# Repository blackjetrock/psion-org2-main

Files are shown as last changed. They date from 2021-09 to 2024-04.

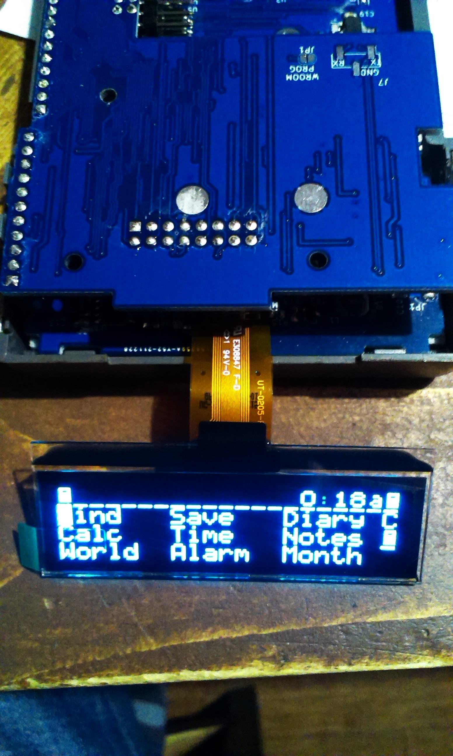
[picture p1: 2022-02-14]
photos/display/IMAG1578.jpg

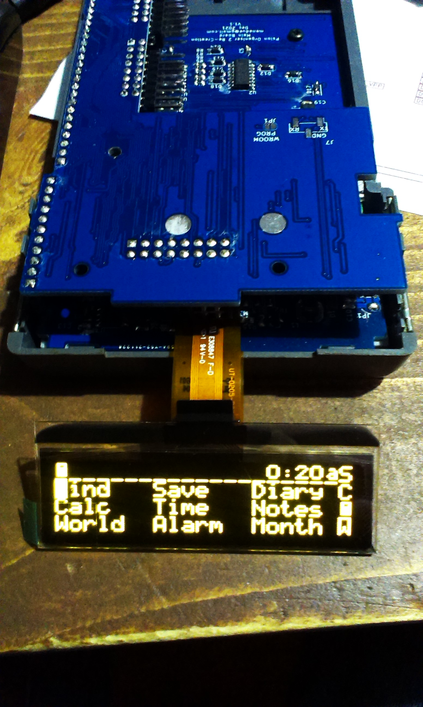
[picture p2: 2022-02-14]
photos/display/IMAG1577.jpg

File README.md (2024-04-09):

# Psion Organiser 2 Recreation Main PCB

A recreation of the Psion Organiser II main PCB using a RP Pico as the
main processor.
An OLED display replaces the original LCD, datapack gadgets supply the
non volatile storage using SD cards.
A ESP-WROOM-32 module on the board provides Wifi and maybe Bluetooth connectivity.
The module provides a hot spot that can be used to perfom actions on the Organiser
and transfer data.

The code running will hopefully be an emulation of the 6303 running one of the original
organiser ROMs with the hardware emulation done on the Pico.

Main PCB
========

This has a RP Pico on it as a controller and several IO expanders. These are because the Pico doesn't have enough GPIOs to
run all of the hardware that is needed.

Power PCB
=========

The original power PCB doesn't really fit with the new main board, so rather than try to work around it, A new PCB is used with the
new main board. It has the slot connectors and any hardware needed to drive them. The slot level shifters are on this board. It would be possible to design a different poiwer PCB that, for example, didn't have slots but had sd cards instead. The hardware for the slots is then replaced by the new PCB, but the main PCB still has whatever circuitry is needed for its own hardware.

Emulator
========

It's a bit of an odd place for it, but there is an emulator here that I used as the basis for the emulator that runs on the recreation. I did the bulk of the work on it on a PC and then moved i tto the Pico. There's now separate code for the Pico as it supports hardware on the main PCB rather than PC based keyboard and display IO. The mon-emulator is a monitored emulator that uses a second emulator to check the operation of mine so that I could find some tricky bugs. The emulator that does the monitoring is the 6303 file from Jaap's Jape emulator, ported to C.

Display
=======

The display is an OLED dot matrix graphics display. I have tried several colours, they all work, the white display is clearest I think.

IMAG1577
IMAG1578
IMAG1580

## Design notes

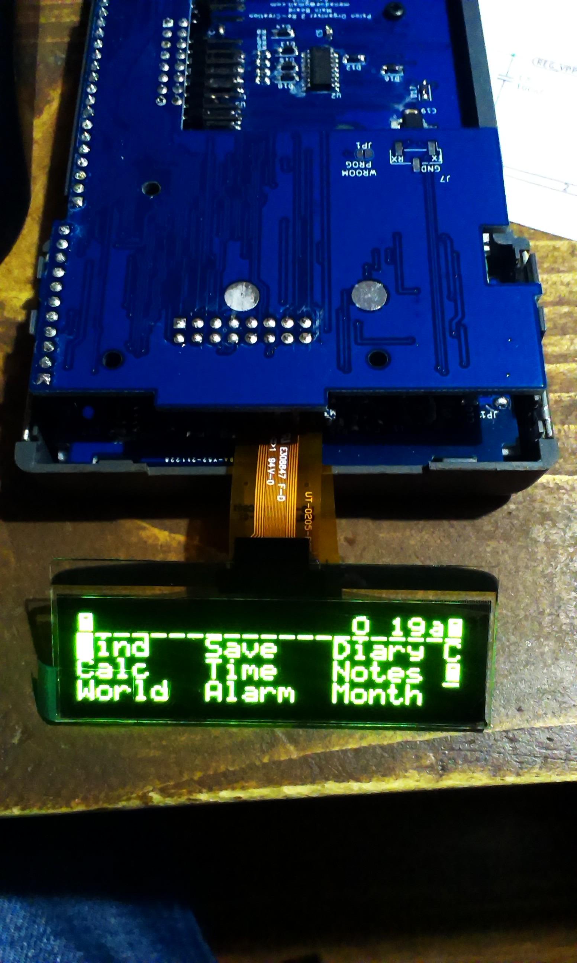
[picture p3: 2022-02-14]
photos/display/IMAG1580.jpg

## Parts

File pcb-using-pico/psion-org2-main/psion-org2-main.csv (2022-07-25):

Id | Designator | Package | Quantity | Designation | Supplier and ref
1 | U5,U2 | SOIC-16_3.9x9.9mm_P1.27mm | 2 | 74HC595
2 | D10,D11 | D_SOD-123 | 2 | 4v7
3 | R18,R25,R15,R10,R24,R14,R13,R1 | R_0805_2012Metric | 8 | 10k
4 | TR1 | SOT-23 | 1 | Si2302CDS-n-ch
5 | D18,D17,D16,D15,D14,D13,D12,D5,D4,D3 | D_SOD-123 | 10 | 1N4148
6 | C7,C6,C5,C22,C3 | C_0805_2012Metric | 5 | 100nF
7 | J3 | PinHeader_1x27_P2.54mm_Vertical | 1 | Conn_01x27_Female
8 | D9,D8 | D_SOD-123 | 2 | AECQ101
9 | J6 | PinHeader_1x11_P2.54mm_Vertical | 1 | Conn_01x11_Female
10 | Y1 | Crystal_SMD_3215-2Pin_3.2x1.5mm | 1 | 32k768Hz
11 | U7 | SO-8_3.9x4.9mm_P1.27mm | 1 | MCP7940N-xSN
12 | R28 | R_0805_2012Metric | 1 | 47k
13 | R27,R11 | R_0805_2012Metric | 2 | 110k
14 | M3,M2,M1 | SOT-23 | 3 | Si2301
15 | D7 | D_SOD-123 | 1 | nopop
16 | C16,C13 | C_0805_2012Metric | 2 | 10pF
17 | TR2 | SOT-23 | 1 | Si2302CDS-n-channel
18 | R17 | R_0805_2012Metric | 1 | nopop
19 | R16 | R_0805_2012Metric | 1 | 2k2
20 | JP6,JP4,JP2 | SolderJumper-2_P1.3mm_Open_RoundedPad1.0x1.5mm | 3 | Jumper_NO_Small
21 | D6 | D_SOD-123 | 1 | 2v7
22 | D2 | D_SOD-123 | 1 | MBR120VLSFT1G
23 | J5,J4 | PinHeader_1x02_P2.54mm_Vertical_SMD_Pin1Left | 2 | Conn_01x02_Female
24 | D1 | D_SOD-123 | 1 | SS36
25 | U4 | SOIC-16_3.9x9.9mm_P1.27mm | 1 | 74LS165
26 | J1 | TE_2-1734839-4_1x24-1MP_P0.5mm_Horizontal_reversed_pinout | 1 | Conn_01x24_Female
27 | SW31 | fx502p_keypad | 1 | right
28 | SW36 | fx502p_keypad | 1 | exe
29 | SW35 | fx502p_keypad | 1 | x
30 | SW34 | fx502p_keypad | 1 | r
31 | SW33 | fx502p_keypad | 1 | L
32 | SW32 | fx502p_keypad | 1 | f
33 | SW30 | fx502p_keypad | 1 | spc
34 | SW29 | fx502p_keypad | 1 | w
35 | SW28 | fx502p_keypad | 1 | q
36 | SW27 | fx502p_keypad | 1 | k
37 | SW26 | fx502p_keypad | 1 | e
38 | SW25 | fx502p_keypad | 1 | left
39 | SW24 | fx502p_keypad | 1 | z
40 | SW23 | fx502p_keypad | 1 | v
41 | SW22 | fx502p_keypad | 1 | p
42 | SW21 | fx502p_keypad | 1 | j
43 | SW20 | fx502p_keypad | 1 | d
44 | SW19 | fx502p_keypad | 1 | down
45 | SW18 | fx502p_keypad | 1 | y
46 | SW17 | fx502p_keypad | 1 | u
47 | SW16 | fx502p_keypad | 1 | o
48 | SW15 | fx502p_keypad | 1 | i
49 | SW14 | fx502p_keypad | 1 | c
50 | SW13 | fx502p_keypad | 1 | up
51 | SW12 | fx502p_keypad | 1 | del
52 | SW11 | fx502p_keypad | 1 | t
53 | SW10 | fx502p_keypad | 1 | n
54 | SW9 | fx502p_keypad | 1 | h
55 | SW8 | fx502p_keypad | 1 | b
56 | SW7 | fx502p_keypad | 1 | mode
57 | SW6 | fx502p_keypad | 1 | shft
58 | SW5 | fx502p_keypad | 1 | s
59 | SW4 | fx502p_keypad | 1 | m
60 | SW3 | fx502p_keypad | 1 | g
61 | SW2 | fx502p_keypad | 1 | A
62 | SW1 | fx502p_keypad | 1 | AC_ON
63 | U1 | RPi_Pico_SMD | 1 | Pico
64 | R21,R20,R19,R9,R8,R7,R6,R5 | R_0805_2012Metric | 8 | 100k
65 | U10 | SOT-223-3_TabPin2 | 1 | AMS1117-3.3
66 | U3 | SOT-23-6 | 1 | Regulator_Switching_MT3608
67 | R23 | R_0805_2012Metric | 1 | Not tested of calculated yet
68 | R22 | R_0805_2012Metric | 1 | Not tested or calculated yet
69 | R12 | R_0805_2012Metric | 1 | 5789R
70 | R4,R3 | R_0805_2012Metric | 2 | 2k
71 | R2 | R_0805_2012Metric | 1 | 910k
72 | L1 | L_Coilcraft_LPS5030 | 1 | 22uH
73 | JP1 | SolderJumper-2_P1.3mm_Open_RoundedPad1.0x1.5mm | 1 | SolderJumper_2_Open
74 | J2 | PinHeader_1x03_P1.00mm_Vertical_SMD_Pin1Left | 1 | Conn_01x03_Female
75 | C21 | C_1210_3225Metric_Pad1.42x2.65mm_HandSolder | 1 | 10uF
76 | C19,C17 | C_0805_2012Metric | 2 | 100n
77 | C10,C4 | C_1210_3225Metric_Pad1.42x2.65mm_HandSolder | 2 | 22uF
78 | C2 | C_0805_2012Metric | 1 | 4u7 25V
79 | C1 | C_0805_2012Metric | 1 | 4u7

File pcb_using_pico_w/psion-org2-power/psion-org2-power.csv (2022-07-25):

Id | Designator | Package | Quantity | Designation | Supplier and ref
1 | J3 | PinHeader_1x27_P2.54mm_Vertical | 1 | Conn_01x27_Female
2 | J9,J8 | psion_beeper_pad | 2 | Conn_01x01_Female
3 | U8 | SOT-223-3_TabPin2 | 1 | AMS1117-5.0
4 | TR3,TR1 | SOT-23 | 2 | Si2302CDS-n-channel
5 | TR2 | SOT-23 | 1 | Si2302CDS-n-ch
6 | R17,R16,R14,R13,R1,R2 | R_0805_2012Metric | 6 | 10k
7 | R12,R11,R10,R9,R8,R7,R6,R5,R4,R3,R15 | R_0805_2012Metric | 11 | 100k
8 | M2,M1 | SOT-23 | 2 | P-CHANNEL-MOSFET
9 | JP1 | SolderJumper-2_P1.3mm_Open_RoundedPad1.0x1.5mm | 1 | Jumper_NO_Small
10 | J7 | PinHeader_1x03_P2.54mm_Vertical_SMD_Pin1Left | 1 | Conn_01x03_Female
11 | D2 | D_SOD-123 | 1 | 4V7
12 | D1 | D_SOD-123 | 1 | 3V0
13 | C12 | C_0805_2012Metric | 1 | 4u7
14 | C11,C10,C9,C7,C8,C6 | C_0805_2012Metric | 6 | 100n
15 | C5,C4,C3,C2,C1 | C_0805_2012Metric | 5 | 100nF
16 | U7,U6 | TSSOP-20_4.4x6.5mm_P0.65mm | 2 | 74LS245
17 | J6 | PinHeader_1x02_P2.54mm_Vertical_SMD_Pin1Left | 1 | Conn_01x02_Female
18 | J1 | PinHeader_2x08_P2.54mm_Horizontal | 1 | Conn_02x08_Odd_Even
19 | J4,J2 | PinHeader_2x08_P2.54mm_Horizontal_psionSide | 2 | Conn_02x08_Odd_Even
20 | U4,U3 | SOIC-8_3.9x4.9mm_P1.27mm | 2 | CAT24C256
21 | U5 | SOIC-16_3.9x9.9mm_P1.27mm | 1 | 74HC595
22 | J5 | PinHeader_1x11_P2.54mm_Vertical | 1 | Conn_01x11_Female
23 | U2 | SOT-223-3_TabPin2 | 1 | AMS1117-3.3
24 | U1 | ESP32-WROOM-32 | 1 | ESP32-WROOM-32

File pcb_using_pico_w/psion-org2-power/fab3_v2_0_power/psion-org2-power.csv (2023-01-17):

Id | Designator | Package | Quantity | Designation | Supplier and ref
1 | U16 | SOT-23-6 | 1 | Regulator_Switching_MT3608
2 | TR7,TR6,TR2 | SOT-23 | 3 | Si2302CDS-n-ch
3 | R51,R48 | R_0805_2012Metric | 2 | 100R
4 | R50 | R_0805_2012Metric | 1 | 1k2
5 | R49 | R_0805_2012Metric | 1 | 18k
6 | R47 | R_0805_2012Metric | 1 | 5k1
7 | R46 | R_0805_2012Metric | 1 | 180k
8 | R45,R14,R13,R1 | R_0805_2012Metric | 4 | 10k
9 | L2 | L_Coilcraft_LPS5030 | 1 | 22uH
10 | JP7 | SolderJumper-2_P1.3mm_Open_RoundedPad1.0x1.5mm | 1 | SolderJumper_2_Open
11 | JP6 | SolderJumper-2_P1.3mm_Open_RoundedPad1.0x1.5mm | 1 | Jumper_NO_Small
12 | D21 | D_SOD-123 | 1 | SS36
13 | C30,C5,C4 | C_0805_2012Metric | 3 | 100nF
14 | C29 | C_1210_3225Metric_Pad1.33x2.70mm_HandSolder | 1 | 10uF
15 | C28,C27 | C_1210_3225Metric_Pad1.33x2.70mm_HandSolder | 2 | 22uF
16 | J3 | PinHeader_1x27_P2.54mm_Vertical | 1 | Conn_01x27_Female
17 | J9,J8 | psion_beeper_pad | 2 | Conn_01x01_Female
18 | U8 | SOT-223-3_TabPin2 | 1 | AMS1117-5.0
19 | R12,R11,R10,R9,R8,R7,R6,R5,R4,R3,R15 | R_0805_2012Metric | 11 | 100k
20 | D1 | D_SOD-123 | 1 | 3V0
21 | C11,C10,C9,C7,C8,C6 | C_0805_2012Metric | 6 | 100n
22 | U7,U6 | TSSOP-20_4.4x6.5mm_P0.65mm | 2 | 74LS245
23 | M1 | SOT-23 | 1 | P-CHANNEL-MOSFET
24 | TR1 | SOT-23 | 1 | Si2302CDS-n-channel
25 | J6 | PinHeader_1x02_P2.54mm_Vertical_SMD_Pin1Left | 1 | Conn_01x02_Female
26 | J1 | PinHeader_2x08_P2.54mm_Horizontal | 1 | Conn_02x08_Odd_Even
27 | J4,J2 | PinHeader_2x08_P2.54mm_Horizontal_psionSide | 2 | Conn_02x08_Odd_Even
28 | U4,U3 | SOIC-8_3.9x4.9mm_P1.27mm | 2 | CAT24C256
29 | U5 | SOIC-16_3.9x9.9mm_P1.27mm | 1 | 74HC595
30 | J5 | PinHeader_1x11_P2.54mm_Vertical | 1 | Conn_01x11_Female

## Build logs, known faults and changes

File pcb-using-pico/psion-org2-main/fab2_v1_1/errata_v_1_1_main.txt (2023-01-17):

Errata for V1.1 of main PCB
===========================

1. 5V regulator being on power PCB means processor PCB isn't stand alone
   any more as Pico is powered from it. Pico can't use battery voltage.
   I think it could be USB powered in stand alone mode. You'd also
   need a battery though for the other circuitry.
   Or put 5V regulator on processor PCB again?
   Or not have sytand alone any more?
2. R13 should be 10k, due maybe to some leakage across PCB
3. Tracks from R15 to TR2 seems to have leakage on to the gate of TR2,
   causing it to not turn off properly. Changing R13 to 10k and removing
   the track allows TR2 to turn off. re-route track. Chek clearances.
4. R25 has to go to VBAT or there is no voltage to allow the RTC to turn
   on the power
5. 100nF across R13 and R14, and R18. All mosfets.

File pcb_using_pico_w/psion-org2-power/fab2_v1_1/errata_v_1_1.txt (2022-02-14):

Errata for Power PCB V1.1
=========================

1. VPP signal on datapack slots should maybe be +5V
2. Diode fouls top slot plastic. Cut away of plastic needed to get it to
   fit.
3. Mounting hole is about 0.5mm out. Screw can be made to fit but it's not
   perfect.
4. Power PCB may be too short at top as top slot slider doesn't stay in place.

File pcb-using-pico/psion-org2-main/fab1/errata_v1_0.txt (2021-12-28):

V1.0 Psion recreate Main PCB Errata
===================================

DONE SCH     1. S_PGM pin needs to be attached for paged datapacks. Not on edge connector.
                Used pin 10 on edge connector. *added*
DONE     PCB 2. Pin headers don't line up
????         3. Holes missing for top slot Not on main board Done on power PCB
DONE SCH     4. OLED pin 10 should be GND not open.
DONE SCH     5. Top row of keys wired up wrong.
DONE SCH     6. Mislabelled P52 as p52 on keyboard.
DONE SCH     7. Put battery voltage circuit on the 'off' side of ON switch to reduce
                supply current draw when off.
DONE SCH     8. Need a diode on each keyboard drive line to allow shiftkey to work.
DONE SCH     9. Put jumper in so OLED supply can be hard wired to GND. There's about
                3V loss with switch and display doesn't turn off fully anyway. Switched
                3V3 power allows it to be turned off. *removed circuit*
DONE SCH     10. Put jumper for MFP output so it can be disabled. It holds
                 power on when low. Added transistor to prevent VBAT on MFP pin. No jumper
		 as we can leave transistor off if the signal isn't needed. Or resistor.
DONE SCH     11. QH_O not attached to shift register
             12. Possibly put LEDs on the KB side of the PCB for backlighting
???          13. Tie unused 245 inputs? *There isn't one on this PCB*
             14. Put buck boost regulator on for 5V so can run from USB supply? No, create
	         a USB supply that has that circuitry due to space and more fexible that way.
DONE SCH     15. VBAT should come from after the diodes that connect to the battery
                 and the external power connector so we have reverse voltage protection.
		 Maybe some signals should come off the battery and not the diode cathodes?
DONE     PCB 16. Put space around mounting holes
DONE     PCB 17. Top slot moulding doesn't fit, move components so it does.
***          18. AC_B input is wrong polarity. pulling low should turn organiser on.
                 Maybe invert logic of keyboard scanning? Put inverter on the power PCB
		 as it's related to the power circuit and top slot. Not really for main
		 PCB. Saves space on main PCB.
DONE     PCB 19. 22uH inductor needs to move, maybe.
DONE     PCB 20. C14 and C15 are badly placed. Renumbered, added decoiupling caps
DONE SCH     21. Decoupling needed for U2,U4,U5
DONE SCH     22. M1,M3 etc need voltage limiting circuits if external power voltage
                 isn't limited. Alternatively limit external power to 8V or whatever
                 M1 etc can operate with. Or swap those transistors for higher voltage
                 rating of Vgs
DONE SCH     23. RTC_MFP has battery voltage on it.
DONE SCH     24. Battery switching needs to limit Vgs. Power needs to be supported up to
                 14V/17V.
DONE LEAVE   25. Buzzer output is OK. Maybe a faster drive? Works ok. Emulation a bit
	         slow so tones not as high
DONE SCH     26. Run buzzer drive to power PCB
DONE SCH     27. JP8 and JP9 not needed. ON can be powered from battery voltage.
DONE SCH     28. Remove JP10 as can just jumper the diode.
***	     29. Running off 5V would be nice. Put dc-dc etc in power adapter as more
                 customizable and flexible, plus not much room on PCBs now.
DONE SCH PCB 30. Take 5V regulator for slots off main PCB.
	     
Tasks
=====
1. Check all key connections. Done.

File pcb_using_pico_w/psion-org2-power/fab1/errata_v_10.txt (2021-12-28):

V1.0 Psion recreate Power PCB Errata
===================================

DONE SCH     1. S_PGM pin needs to be attached for paged datapacks.
DONE SCH     2. SPGM not on edge connector
DONE SCH PCB 3. Put pads on PCB for beeper springs
             4. Put buck boost for running off USB supply on this PCB? Maybe
	        better on processor PCB? If just for datapacks then power PCB.
		Use external power pack from usb to ext power in.
DONE SCH PCB 5. Pull downs on pack slot connector side of SDx databus
	        lines needed.
DONE SCH PCB 6. Switch supply of WROOM with 2 transistor switch from
	        VBAT_SWITCHED2 into 3V3 regulator.
DONE     PCB 7. Screw post hits U7
****         8. External power filter/protection? No, put on external PSU
DONE SCH     9. Add connections for programming the WROOM
DONE SCH PCB 10. Limit Vgs on mosfets.
DONE SCH     11. IO0 to GND for programming mode
                 TXD0 and RXD0 to RXD and TXD
DONE SCH     12. Tie unused 245 to GND?
DONE SCH     13. Invert EX_ON signal. VBAT powered.
DONE SCH     14. Buzzer signal run in to board pin 14
DONE SCH     15. Why is 5V regulator on processor PCB? It powers the slots and
		 they are a power PCB funtion.
DONE         16. Check outline of top slot plastic moulding

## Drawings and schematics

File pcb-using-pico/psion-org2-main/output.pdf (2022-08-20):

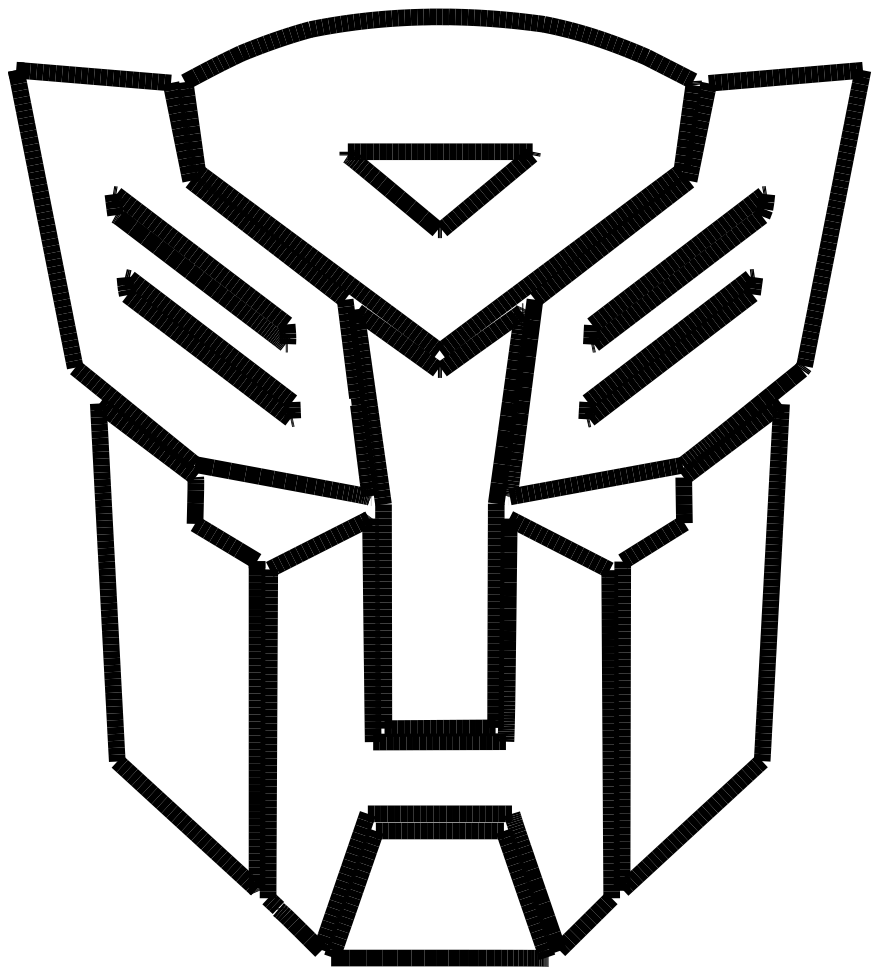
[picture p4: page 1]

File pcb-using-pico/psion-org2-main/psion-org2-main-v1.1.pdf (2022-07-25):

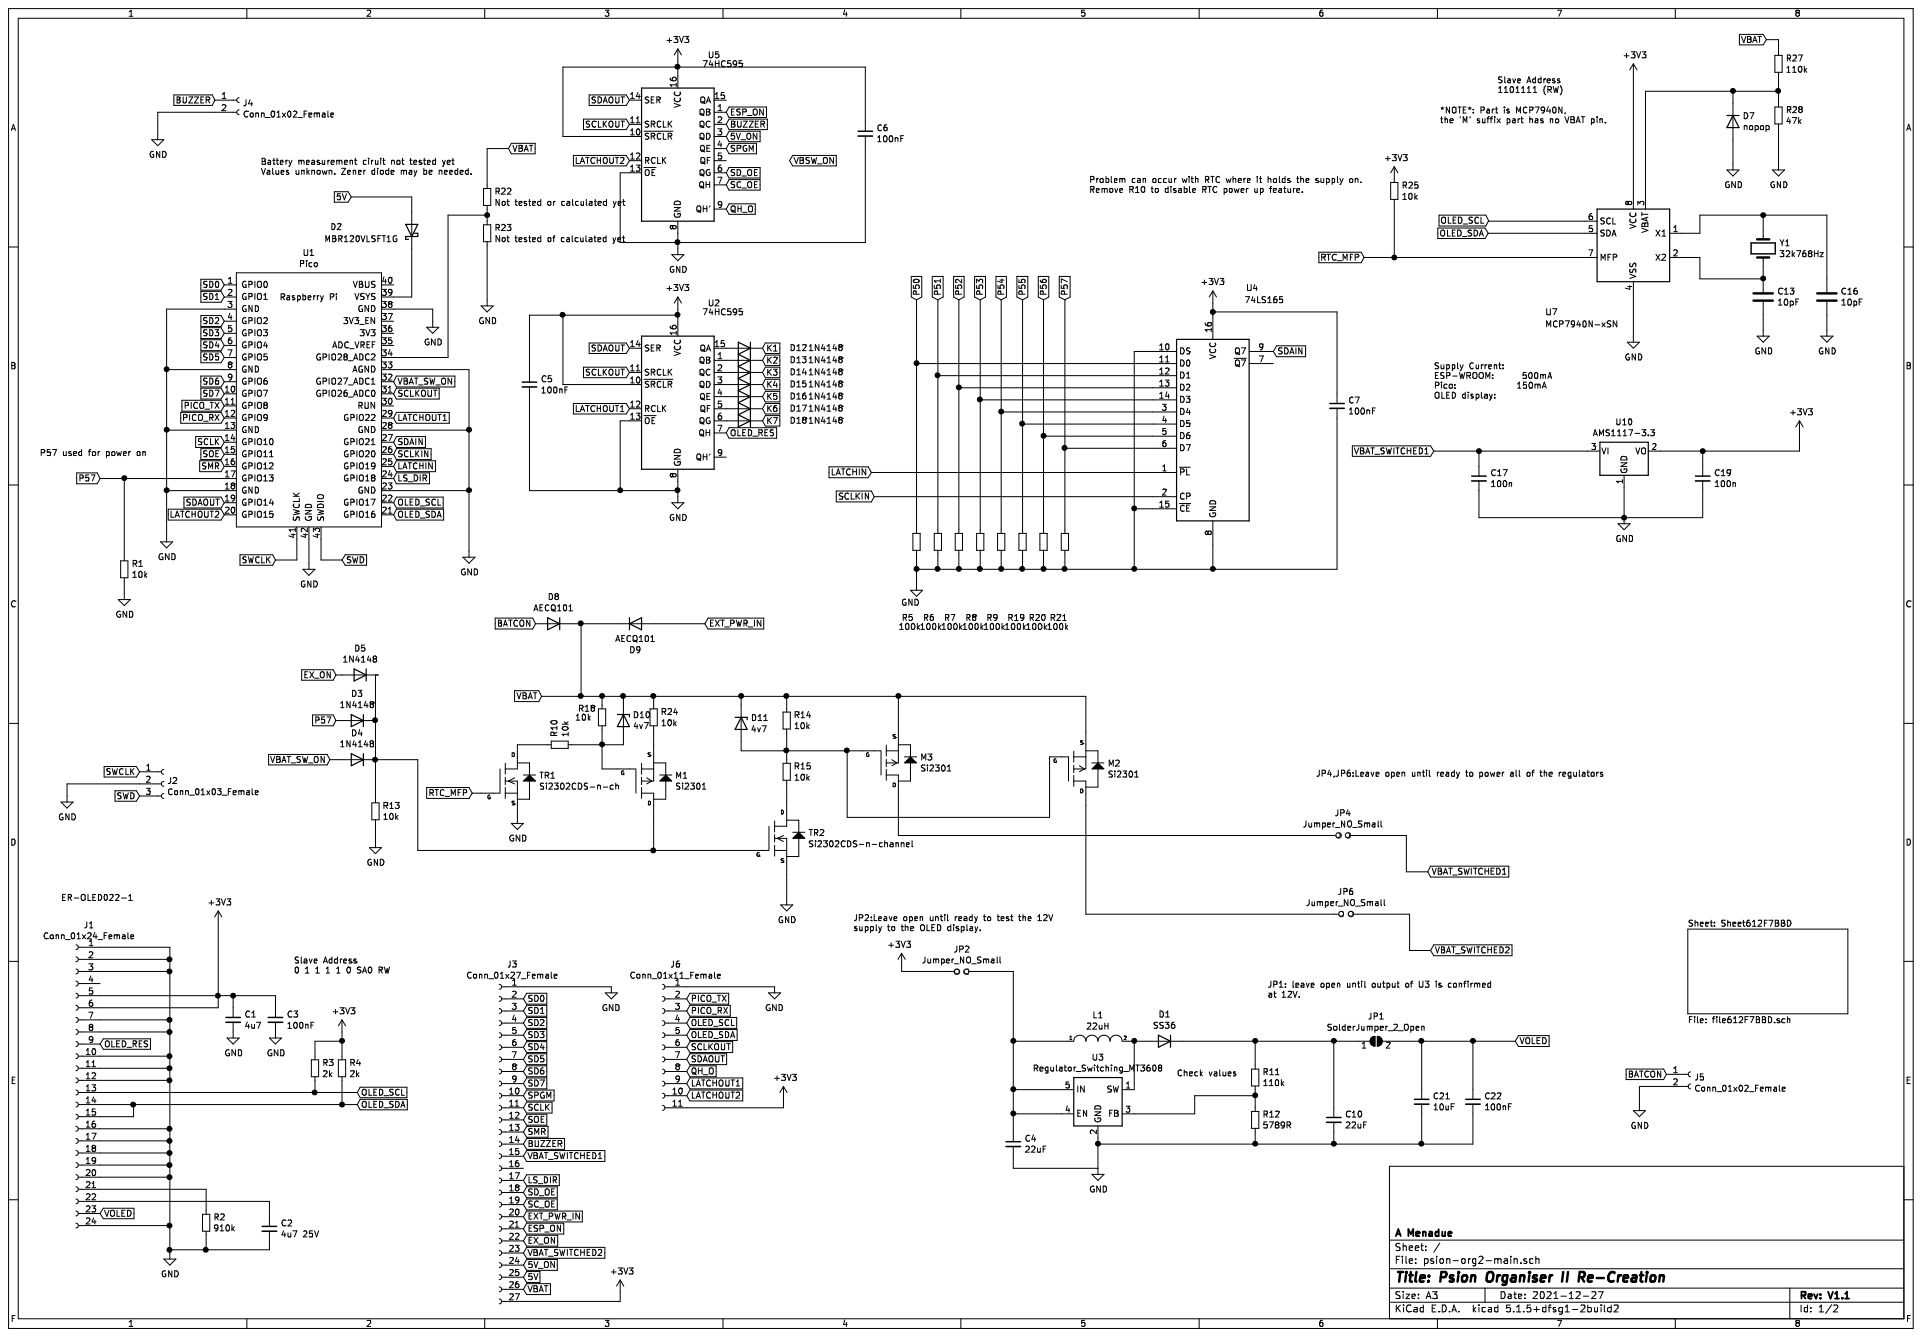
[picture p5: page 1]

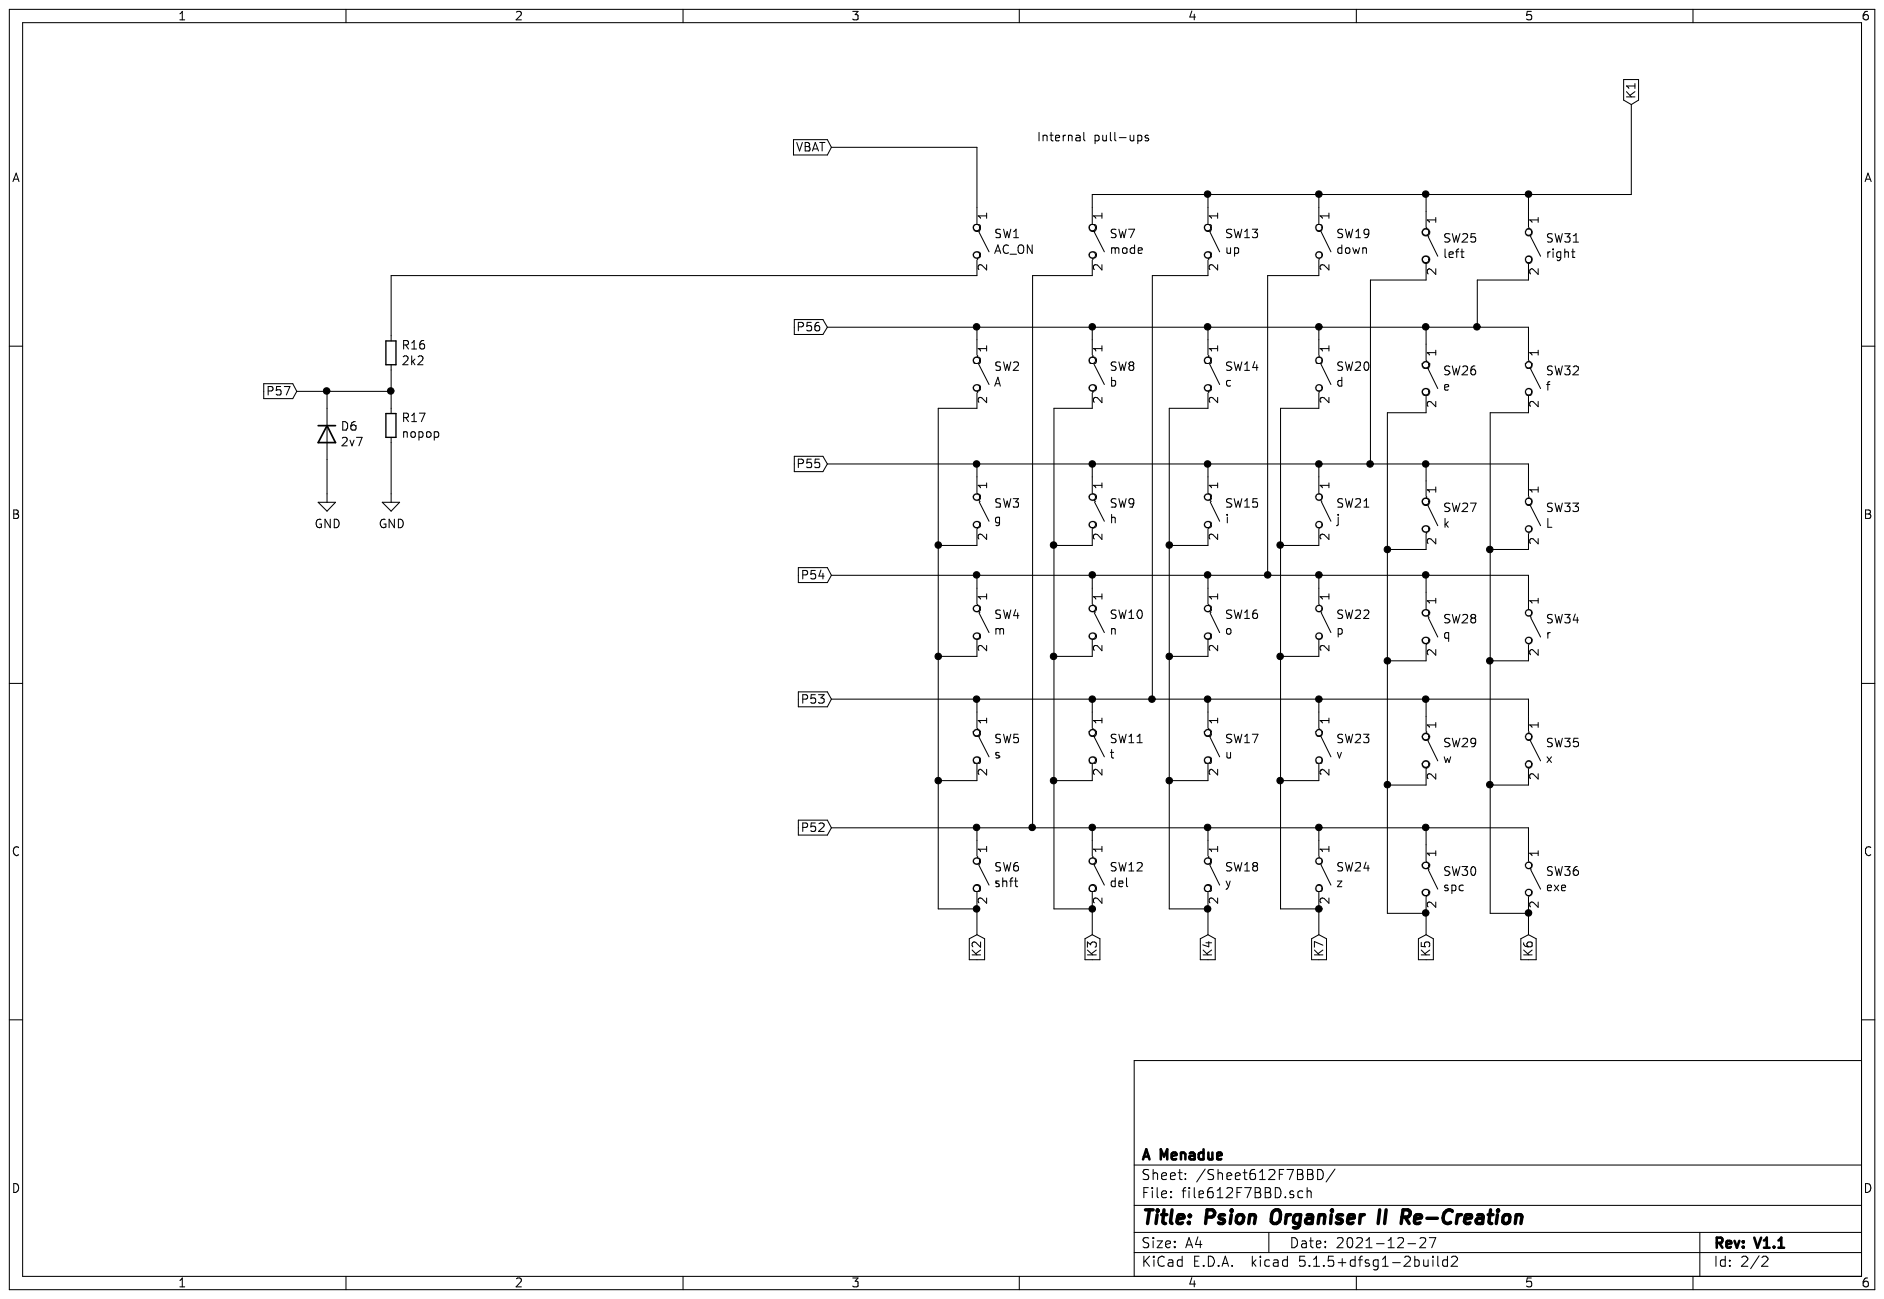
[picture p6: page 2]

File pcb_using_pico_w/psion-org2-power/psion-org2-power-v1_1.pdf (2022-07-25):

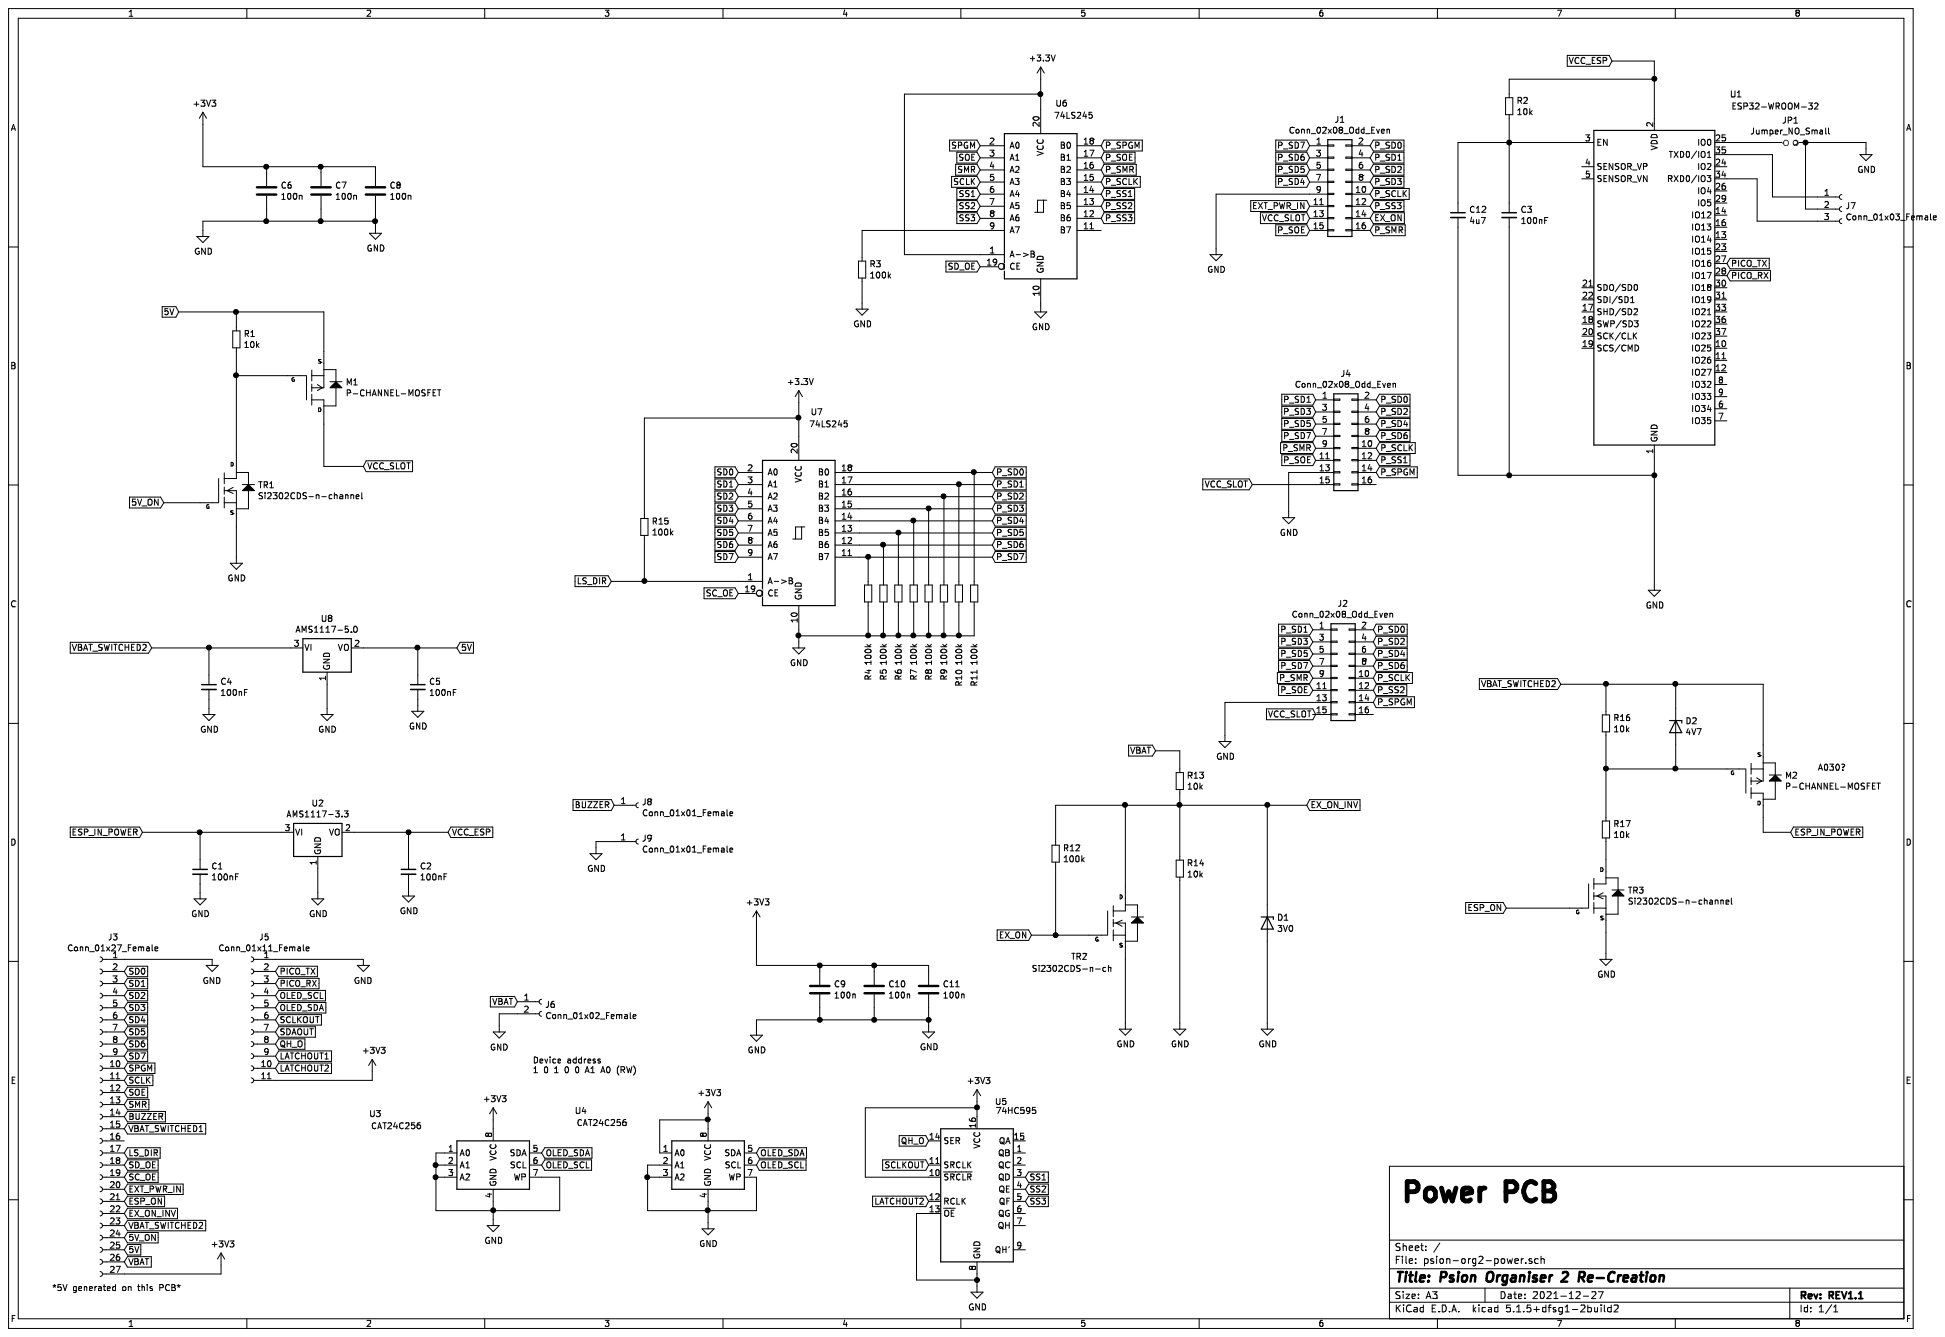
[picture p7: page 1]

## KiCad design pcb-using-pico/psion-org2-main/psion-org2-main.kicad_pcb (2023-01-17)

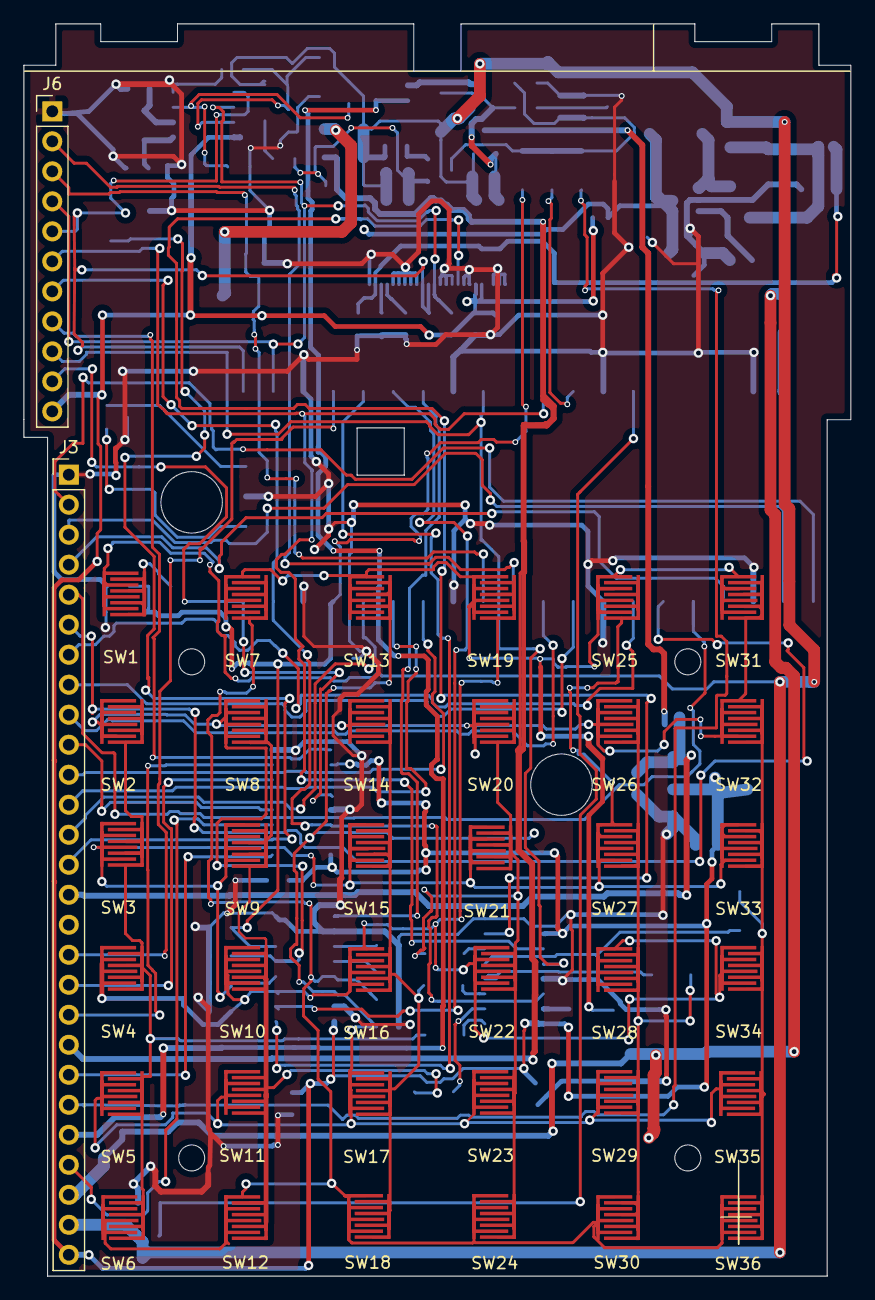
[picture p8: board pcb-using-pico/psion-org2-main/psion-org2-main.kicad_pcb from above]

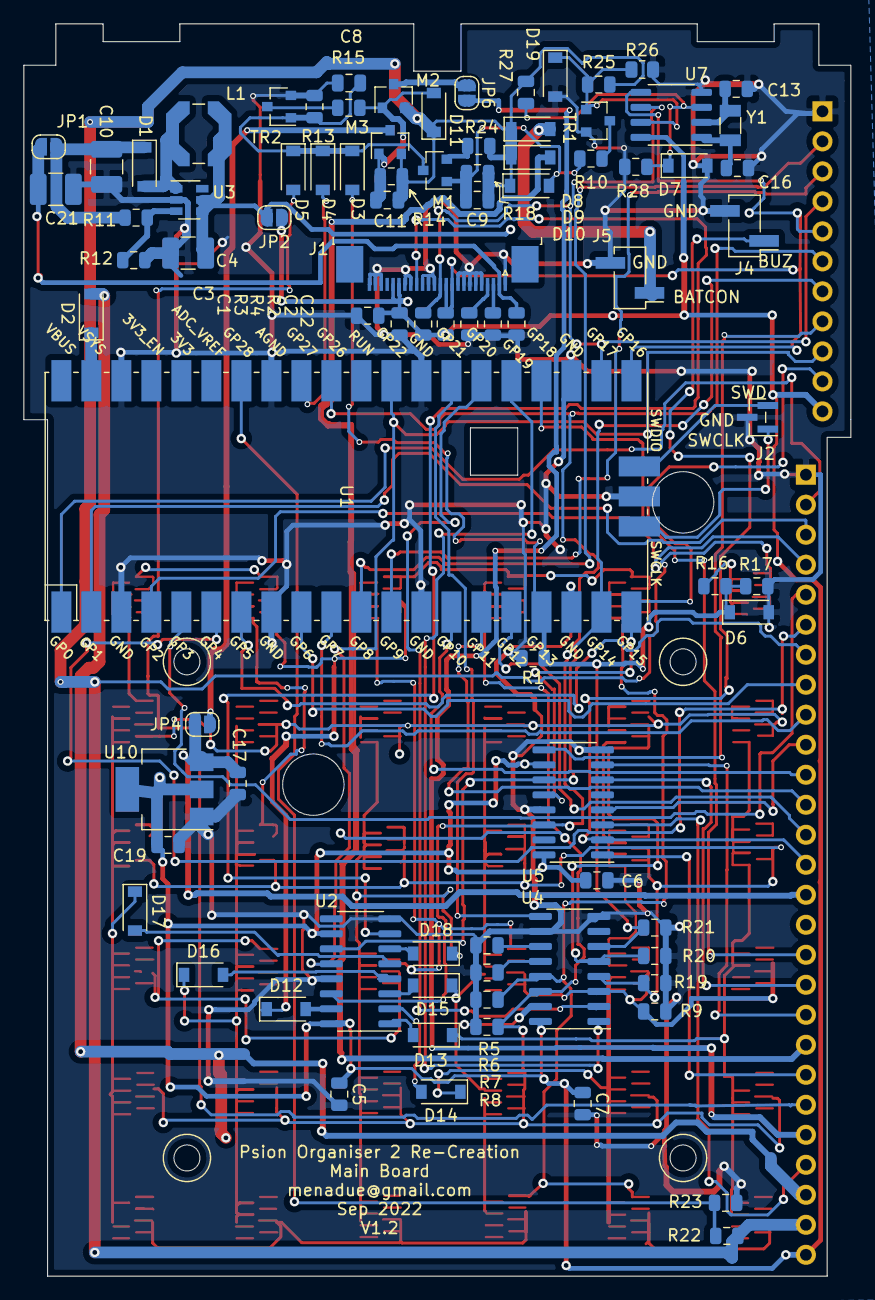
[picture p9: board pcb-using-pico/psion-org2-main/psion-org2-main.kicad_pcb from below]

Board: 2 copper layers, 70.0 x 106.0 mm, 124 parts (86 on the bottom side), 87 nets.

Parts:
C1: 4u7; C_0805_2012Metric
C2: 4u7 25V; C_0805_2012Metric
C3, C5, C6, C7, C8, C9, C11, C22: 100nF; C_0805_2012Metric
C4, C10: 22uF; C_1210_3225Metric_Pad1.42x2.65mm_HandSolder
C13, C16: 10pF; C_0805_2012Metric
C17, C19: 100n; C_0805_2012Metric
C21: 10uF; C_1210_3225Metric_Pad1.42x2.65mm_HandSolder
D1: SS36; D_SOD-123
D2: MBR120VLSFT1G; D_SOD-123
D3, D4, D5, D12, D13, D14, D15, D16, D17, D18: 1N4148; D_SOD-123
D6: 2v7; D_SOD-123
D7, D19: nopop; D_SOD-123
D8, D9: AECQ101; D_SOD-123
D10, D11: 4v7; D_SOD-123
J1: Conn_01x24_Female; TE_2-1734839-4_1x24-1MP_P0.5mm_Horizontal_reversed_pinout
J2: Conn_01x03_Female; PinHeader_1x03_P1.00mm_Vertical_SMD_Pin1Left
J3: Conn_01x27_Female; PinHeader_1x27_P2.54mm_Vertical
J4, J5: Conn_01x02_Female; PinHeader_1x02_P2.54mm_Vertical_SMD_Pin1Left
J6: Conn_01x11_Female; PinHeader_1x11_P2.54mm_Vertical
JP1: SolderJumper_2_Open; SolderJumper-2_P1.3mm_Open_RoundedPad1.0x1.5mm
JP2, JP4, JP6: Jumper_NO_Small; SolderJumper-2_P1.3mm_Open_RoundedPad1.0x1.5mm
L1: 22uH; L_Coilcraft_LPS5030
M1, M2, M3: Si2301; SOT-23
R1, R10, R13, R14, R15, R18, R24, R25, R26: 10k; R_0805_2012Metric
R2: 910k; R_0805_2012Metric
R3, R4: 2k; R_0805_2012Metric
R5, R6, R7, R8, R9, R19, R20, R21: 100k; R_0805_2012Metric
R11, R27: 110k; R_0805_2012Metric
R12: 5789R; R_0805_2012Metric
R16: 2k2; R_0805_2012Metric
R17: nopop; R_0805_2012Metric
R22: Not tested or calculated yet; R_0805_2012Metric
R23: Not tested of calculated yet; R_0805_2012Metric
R28: 47k; R_0805_2012Metric
SW1: AC_ON; fx502p_keypad
SW2: A; fx502p_keypad
SW3: g; fx502p_keypad
SW4: m; fx502p_keypad
SW5: s; fx502p_keypad
SW6: shft; fx502p_keypad
SW7: mode; fx502p_keypad
SW8: b; fx502p_keypad
SW9: h; fx502p_keypad
SW10: n; fx502p_keypad
SW11: t; fx502p_keypad
SW12: del; fx502p_keypad
SW13: up; fx502p_keypad
SW14: c; fx502p_keypad
SW15: i; fx502p_keypad
SW16: o; fx502p_keypad
SW17: u; fx502p_keypad
SW18: y; fx502p_keypad
SW19: down; fx502p_keypad
SW20: d; fx502p_keypad
SW21: j; fx502p_keypad
SW22: p; fx502p_keypad
SW23: v; fx502p_keypad
SW24: z; fx502p_keypad
SW25: left; fx502p_keypad
SW26: e; fx502p_keypad
SW27: k; fx502p_keypad
SW28: q; fx502p_keypad
SW29: w; fx502p_keypad
SW30: spc; fx502p_keypad
SW31: right; fx502p_keypad
SW32: f; fx502p_keypad
SW33: L; fx502p_keypad
SW34: r; fx502p_keypad
SW35: x; fx502p_keypad
SW36: exe; fx502p_keypad
TR1: Si2302CDS-n-ch; SOT-23
TR2: Si2302CDS-n-channel; SOT-23
U1: Pico; RPi_Pico_SMD
U2, U5: 74HC595; SOIC-16_3.9x9.9mm_P1.27mm
U3: Regulator_Switching_MT3608; SOT-23-6
U4: 74LS165; SOIC-16_3.9x9.9mm_P1.27mm
U7: MCP7940N-xSN; SO-8_3.9x4.9mm_P1.27mm
U10: AMS1117-3.3; SOT-223-3_TabPin2
Y1: 32k768Hz; Crystal_SMD_3215-2Pin_3.2x1.5mm

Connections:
5V: D2.2, J3.25
5V_ON: J3.24, U5.3
+3V3: C1.1, C3.1, C5.1, C6.1, C7.1, C19.1, J1.5, J1.6, J3.27, J6.11, JP2.1, R3.1, R4.1, U2.10, U2.16, U4.16, U5.10, U5.16, U7.8, U10.2
BATCON: D8.2, J5.1
BUZZER: J3.14, J4.1, U5.2
ESP_ON: J3.21, U5.1
EXT_PWR_IN: D9.2, J3.20
EX_ON: D5.2, J3.22
GND: C1.2, C2.2, C3.2, C4.2, C5.2, C6.2, C7.2, C8.2, C10.2, C13.2, C16.2, C17.2, C19.2, C21.2, C22.2, D6.2, D7.2, D19.2, J1.1, J1.2, J1.3, J1.7, J1.8, J1.10, J1.11, J1.12, J1.16, J1.17, J1.18, J1.19, J1.20, J1.24, J2.2, J3.1, J4.2, J5.2, J6.1, R1.2, R2.2, R5.2, R6.2, R7.2, R8.2, R9.2, R12.2, R13.2, R17.2, R19.2, R20.2, R21.2, R23.2, R26.2, R28.2, TR1.2, TR2.2, U1.3, U1.8, U1.13, U1.18, U1.23, U1.28, U1.33, U1.38, U1.42, U2.8, U2.13, U3.2, U4.8, U4.10, U4.15, U5.8, U5.13, U7.4, U10.1
K1: D12.1, SW7.1, SW13.1, SW19.1, SW25.1, SW31.1
K2: D13.1, SW2.2, SW3.2, SW4.2, SW5.2, SW6.2
K3: D14.1, SW8.2, SW9.2, SW10.2, SW11.2, SW12.2
K4: D15.1, SW14.2, SW15.2, SW16.2, SW17.2, SW18.2
K5: D16.1, SW26.2, SW27.2, SW28.2, SW29.2, SW30.2
K6: D17.1, SW32.2, SW33.2, SW34.2, SW35.2, SW36.2
K7: D18.1, SW20.2, SW21.2, SW22.2, SW23.2, SW24.2
LATCHIN: U1.25, U4.1
LATCHOUT1: J6.9, U1.29, U2.12
LATCHOUT2: J6.10, U1.20, U5.12
LS_DIR: J3.17, U1.24
unnamed: C2.1, J1.22
unnamed: C4.1, JP2.2, L1.1, U3.4, U3.5
unnamed: C8.1, D3.1, D4.1, D5.1, M1.3, R13.1, TR2.1
unnamed: C9.2, D10.2, M1.1, R10.2, R18.2
unnamed: C10.1, D1.1, JP1.1, R11.1
unnamed: C11.2, D11.2, M2.1, M3.1, R14.2, R15.1
unnamed: C13.1, U7.2, Y1.2
unnamed: C16.1, U7.1, Y1.1
unnamed: D1.2, L1.2, U3.1
unnamed: D2.1, U1.39
unnamed: D7.1, R27.2, R28.1, U7.3
unnamed: D12.2, U2.15
unnamed: D13.2, U2.1
unnamed: D14.2, U2.2
unnamed: D15.2, U2.3
unnamed: D16.2, U2.4
unnamed: D17.2, U2.5
unnamed: D18.2, U2.6
unnamed: J1.21, R2.1
unnamed: JP4.1, M3.3
unnamed: JP6.1, M2.3
unnamed: M1.2, R24.2
unnamed: R10.1, TR1.3
unnamed: R11.2, R12.1, U3.3
unnamed: R15.2, TR2.3
unnamed: R16.1, SW1.2
unnamed: R22.2, R23.1, U1.34
OLED_RES: J1.9, U2.7
OLED_SCL: J1.13, J6.4, R3.2, U1.22, U7.6
OLED_SDA: J1.14, J1.15, J6.5, R4.2, U1.21, U7.5
P50: R5.1, U4.11
P51: R6.1, U4.12
P52: R7.1, SW6.1, SW7.2, SW12.1, SW18.1, SW24.1, SW30.1, SW36.1, U4.13
P53: R8.1, SW5.1, SW11.1, SW13.2, SW17.1, SW23.1, SW29.1, SW35.1, U4.14
P54: R9.1, SW4.1, SW10.1, SW16.1, SW19.2, SW22.1, SW28.1, SW34.1, U4.3
P55: R19.1, SW3.1, SW9.1, SW15.1, SW21.1, SW25.2, SW27.1, SW33.1, U4.4
P56: R20.1, SW2.1, SW8.1, SW14.1, SW20.1, SW26.1, SW31.2, SW32.1, U4.5
P57: D3.2, D6.1, R1.1, R16.2, R17.1, R21.1, U1.17, U4.6
PICO_RX: J6.3, U1.12
PICO_TX: J6.2, U1.11
QH_O: J6.8, U5.9
RTC_MFP: D19.1, R25.2, R26.1, TR1.1, U7.7
SCLK: J3.11, U1.14
SCLKIN: U1.26, U4.2
SCLKOUT: J6.6, U1.31, U2.11, U5.11
SC_OE: J3.19, U5.7
SD0: J3.2, U1.1
SD1: J3.3, U1.2
SD2: J3.4, U1.4
SD3: J3.5, U1.5
SD4: J3.6, U1.6
SD5: J3.7, U1.7
SD6: J3.8, U1.9
SD7: J3.9, U1.10
SDAIN: U1.27, U4.9
SDAOUT: J6.7, U1.19, U2.14, U5.14
SD_OE: J3.18, U5.6
SMR: J3.13, U1.16
SOE: J3.12, U1.15
SPGM: J3.10, U5.4
SWCLK: J2.1, U1.41
SWD: J2.3, U1.43
VBAT: C9.1, C11.1, D8.1, D9.1, D10.1, D11.1, J3.26, M2.2, M3.2, R14.1, R18.1, R22.1, R24.1, R25.1, R27.1, SW1.1
VBAT_SWITCHED1: C17.1, J3.15, JP4.2, U10.3
VBAT_SWITCHED2: J3.23, JP6.2
VBAT_SW_ON: D4.2, U1.32
VOLED: C21.1, C22.1, J1.23, JP1.2

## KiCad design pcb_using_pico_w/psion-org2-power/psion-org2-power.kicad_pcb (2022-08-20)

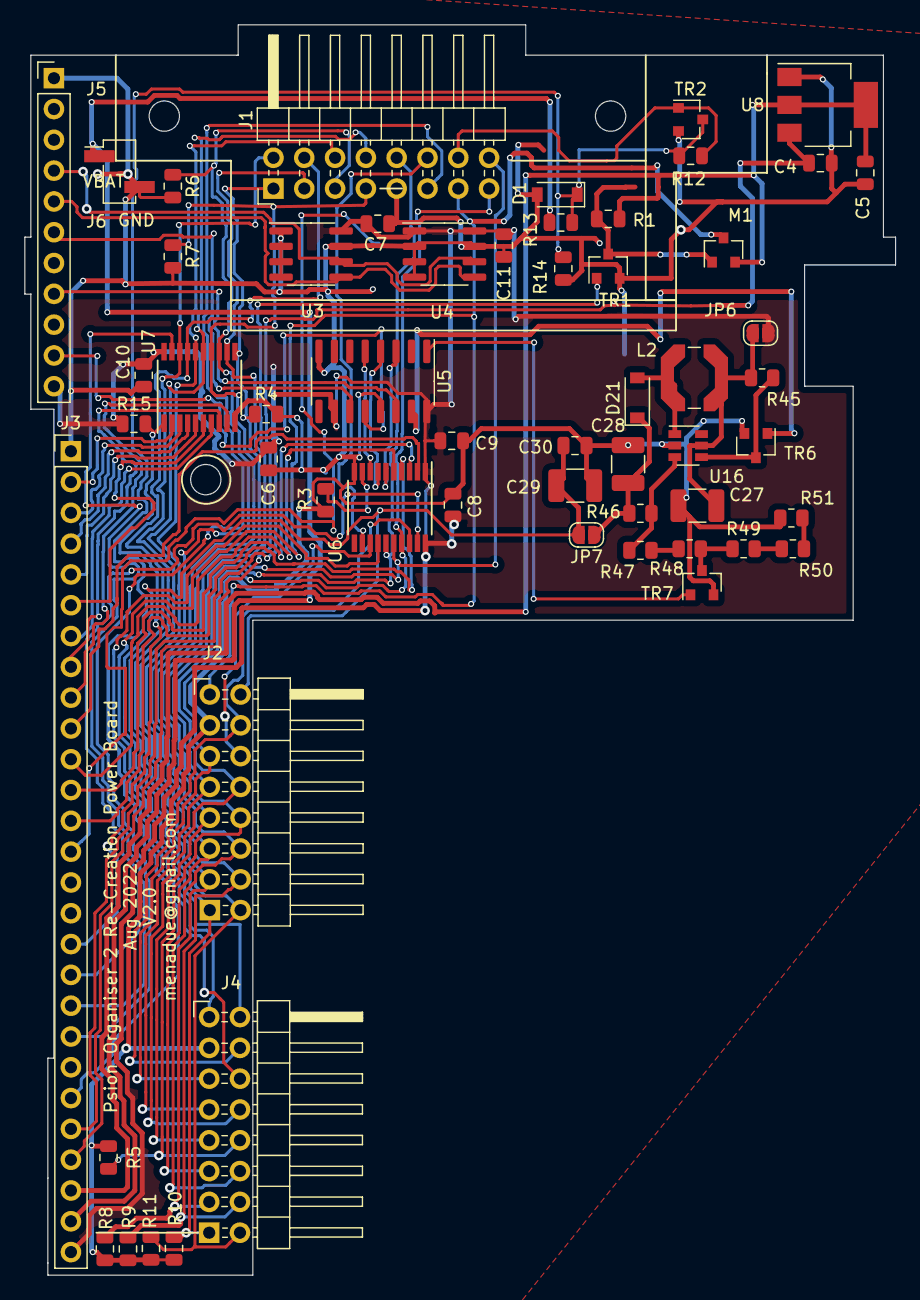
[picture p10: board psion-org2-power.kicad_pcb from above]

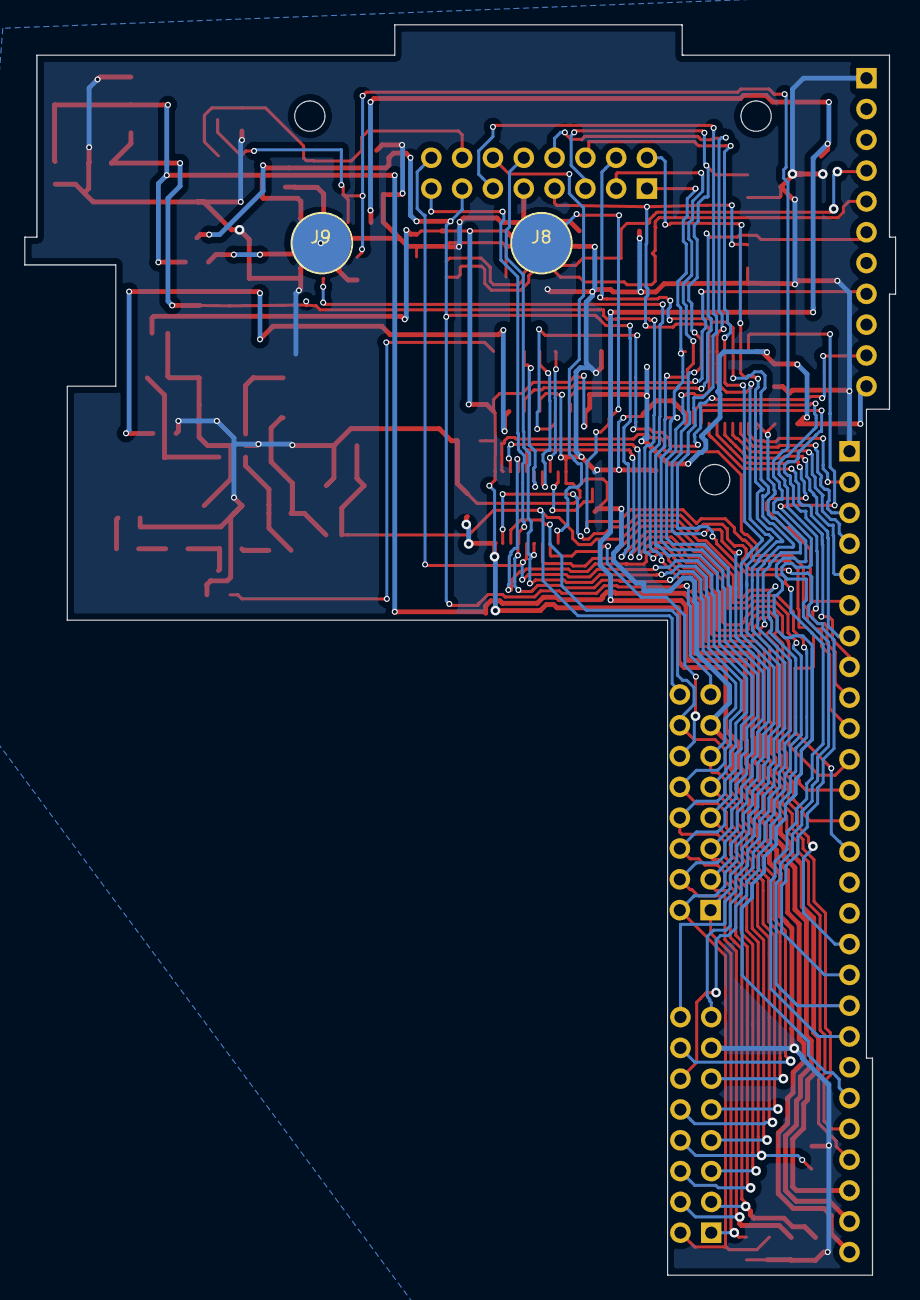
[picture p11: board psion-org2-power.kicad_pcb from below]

Board: 2 copper layers, 71.8 x 103.1 mm, 58 parts (2 on the bottom side), 63 nets.

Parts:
C4, C5, C30: 100nF; C_0805_2012Metric
C6, C7, C8, C9, C10, C11: 100n; C_0805_2012Metric
C27, C28: 22uF; C_1210_3225Metric_Pad1.33x2.70mm_HandSolder
C29: 10uF; C_1210_3225Metric_Pad1.33x2.70mm_HandSolder
D1: 3V0; D_SOD-123
D21: SS36; D_SOD-123
J1: Conn_02x08_Odd_Even; PinHeader_2x08_P2.54mm_Horizontal
J2, J4: Conn_02x08_Odd_Even; PinHeader_2x08_P2.54mm_Horizontal_psionSide
J3: Conn_01x27_Female; PinHeader_1x27_P2.54mm_Vertical
J5: Conn_01x11_Female; PinHeader_1x11_P2.54mm_Vertical
J6: Conn_01x02_Female; PinHeader_1x02_P2.54mm_Vertical_SMD_Pin1Left
J8, J9: Conn_01x01_Female; psion_beeper_pad
JP6: Jumper_NO_Small; SolderJumper-2_P1.3mm_Open_RoundedPad1.0x1.5mm
JP7: SolderJumper_2_Open; SolderJumper-2_P1.3mm_Open_RoundedPad1.0x1.5mm
L2: 22uH; L_Coilcraft_LPS5030
M1: P-CHANNEL-MOSFET; SOT-23
R1, R13, R14, R45: 10k; R_0805_2012Metric
R3, R4, R5, R6, R7, R8, R9, R10, R11, R12, R15: 100k; R_0805_2012Metric
R46: 180k; R_0805_2012Metric
R47: 5k1; R_0805_2012Metric
R48, R51: 100R; R_0805_2012Metric
R49: 18k; R_0805_2012Metric
R50: 1k2; R_0805_2012Metric
TR1: Si2302CDS-n-channel; SOT-23
TR2, TR6, TR7: Si2302CDS-n-ch; SOT-23
U3, U4: CAT24C256; SOIC-8_3.9x4.9mm_P1.27mm
U5: 74HC595; SOIC-16_3.9x9.9mm_P1.27mm
U6, U7: 74LS245; TSSOP-20_4.4x6.5mm_P0.65mm
U8: AMS1117-5.0; SOT-223-3_TabPin2
U16: Regulator_Switching_MT3608; SOT-23-6

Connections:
5V: C5.1, J3.25, M1.2, R1.1, U8.2
5V_ON: J3.24, TR1.1
+3V3: C6.1, C7.1, C8.1, C9.1, C10.1, C11.1, J3.27, J5.11, JP6.1, R15.1, U3.8, U4.1, U4.8, U5.10, U5.16, U6.1, U6.20, U7.20
BUZZER: J3.14, J8.1
EXT_PWR_IN: J1.11, J3.20
EX_ON: J1.14, R12.2, TR2.1
EX_ON_INV: D1.1, J3.22, R12.1, R13.2, R14.1, TR2.3
GND: C4.2, C5.2, C6.2, C7.2, C8.2, C9.2, C10.2, C11.2, C27.2, C28.2, C29.2, C30.2, D1.2, J1.9, J2.13, J3.1, J4.13, J5.1, J6.2, J9.1, R3.2, R4.2, R5.2, R6.2, R7.2, R8.2, R9.2, R10.2, R11.2, R14.2, R51.2, TR1.2, TR2.2, TR6.2, TR7.2, U3.1, U3.2, U3.3, U3.4, U3.7, U4.2, U4.3, U4.4, U4.7, U5.8, U5.13, U6.10, U7.10, U8.1, U16.2
LATCHOUT2: J5.10, U5.12
LS_DIR: J3.17, R15.2, U7.1
unnamed: C27.1, JP6.2, L2.1, R45.1, U16.5
unnamed: C28.1, D21.1, JP7.1, R46.1
unnamed: D21.2, L2.2, U16.1
unnamed: M1.1, R1.2, TR1.3
unnamed: R3.1, U6.9
unnamed: R45.2, TR6.3, U16.4
unnamed: R46.2, R47.1, U16.3
unnamed: R47.2, R48.1
unnamed: R48.2, R49.1, TR7.3
unnamed: R49.2, R50.1
unnamed: R50.2, R51.1
OLED_SCL: J5.4, U3.6, U4.6
OLED_SDA: J5.5, U3.5, U4.5
P_SCLK: J1.10, J2.10, J4.10, U6.15
P_SD0: J1.2, J2.2, J4.2, R11.1, U7.18
P_SD1: J1.4, J2.1, J4.1, R10.1, U7.17
P_SD2: J1.6, J2.4, J4.4, R9.1, U7.16
P_SD3: J1.8, J2.3, J4.3, R8.1, U7.15
P_SD4: J1.7, J2.6, J4.6, R7.1, U7.14
P_SD5: J1.5, J2.5, J4.5, R6.1, U7.13
P_SD6: J1.3, J2.8, J4.8, R5.1, U7.12
P_SD7: J1.1, J2.7, J4.7, R4.1, U7.11
P_SMR: J1.16, J2.9, J4.9, U6.16
P_SOE: J1.15, J2.11, J4.11, U6.17
P_SPGM: J2.14, J4.14, U6.18
P_SS1: J4.12, U6.14
P_SS2: J2.12, U6.13
P_SS3: J1.12, U6.12
QH_O: J5.8, U5.14
SCLK: J3.11, U6.5
SCLKOUT: J5.6, U5.11
SC_OE: J3.19, U7.19
SD0: J3.2, U7.2
SD1: J3.3, U7.3
SD2: J3.4, U7.4
SD3: J3.5, U7.5
SD4: J3.6, U7.6
SD5: J3.7, U7.7
SD6: J3.8, U7.8
SD7: J3.9, U7.9
SD_OE: J3.18, U6.19
SMR: J3.13, U6.4
SOE: J3.12, U6.3
SPGM: J3.10, U6.2
SS1: U5.3, U6.6
SS2: U5.4, U6.7
SS3: U5.5, U6.8
VBAT: J3.26, J6.1, R13.1
VBAT_SWITCHED2: C4.1, J3.23, U8.3
VCC_SLOT: J1.13, J2.15, J4.15, M1.3
VPP_DRIVE: C29.1, C30.1, J2.16, J4.16, JP7.2
VPP_ON: TR6.1, U5.15
VPP_VOLT_SELECT: TR7.1, U5.1

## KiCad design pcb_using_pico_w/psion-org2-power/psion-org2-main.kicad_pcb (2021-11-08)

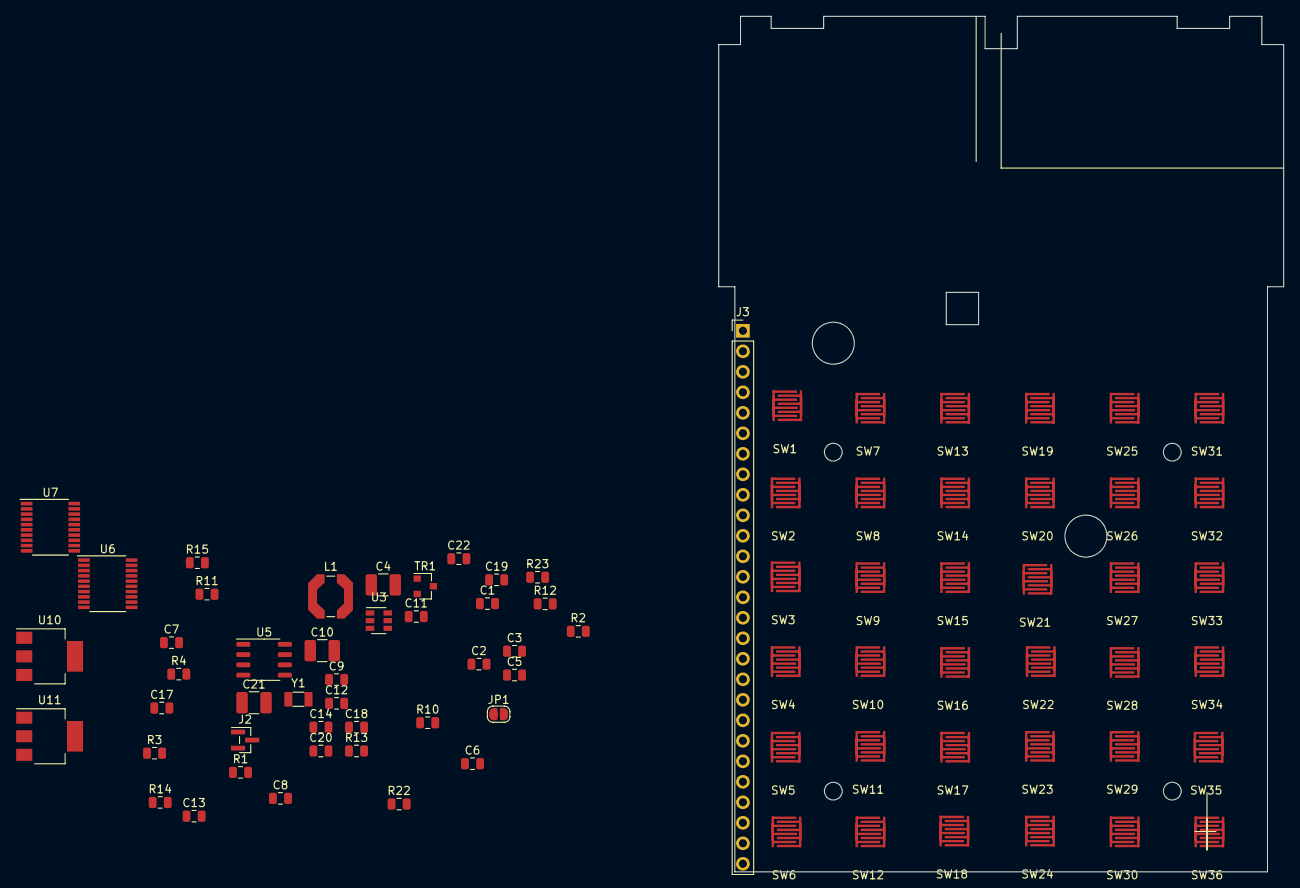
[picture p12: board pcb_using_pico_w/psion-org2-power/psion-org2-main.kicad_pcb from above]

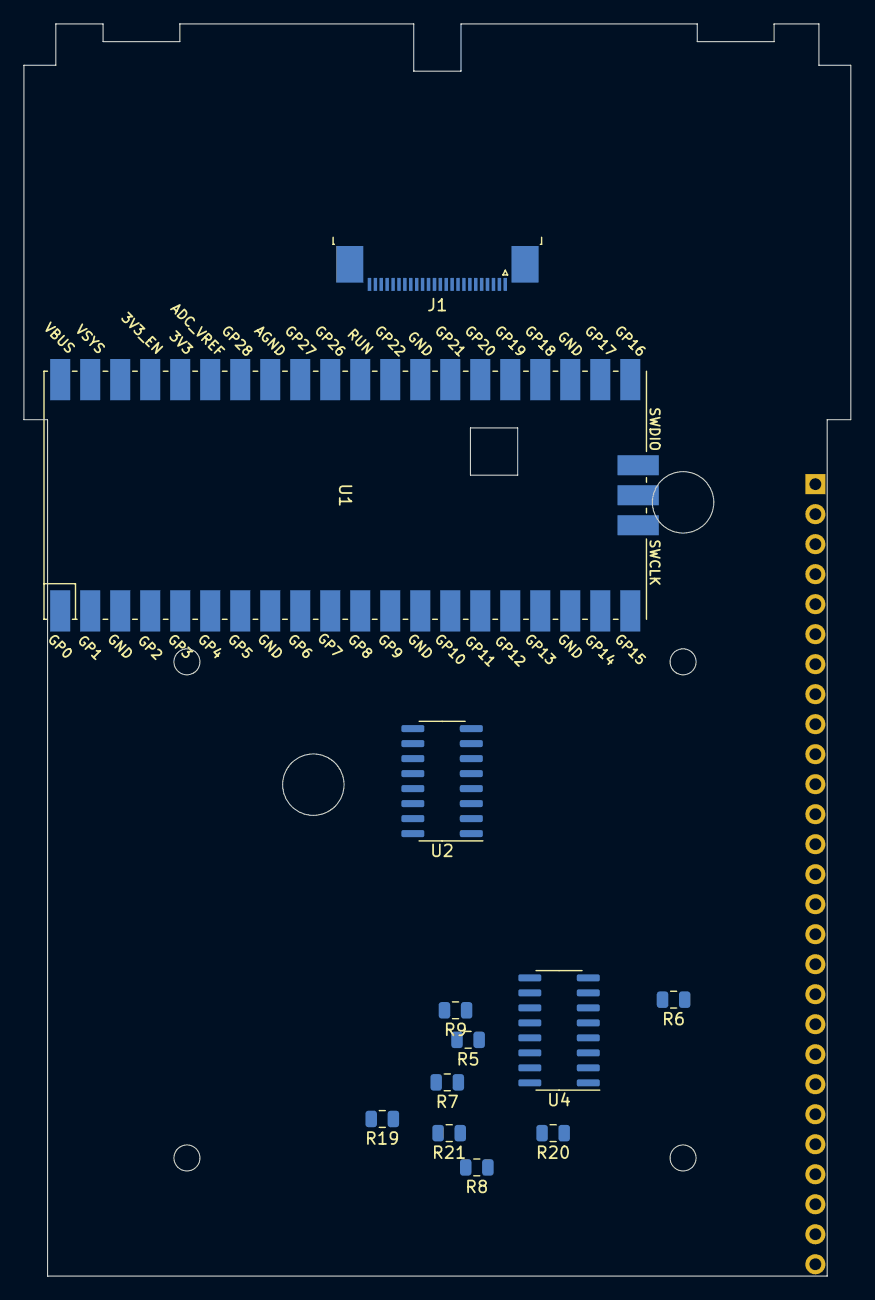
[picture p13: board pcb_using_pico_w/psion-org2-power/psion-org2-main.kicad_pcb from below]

Board: 2 copper layers, 70.0 x 106.0 mm, 92 parts (12 on the bottom side), 73 nets, no tracks yet.

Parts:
C1: 4u7; C_0805_2012Metric
C2: 4u7 25V; C_0805_2012Metric
C3, C22: 100nF; C_0805_2012Metric
C4, C10: 22uF; C_1210_3225Metric_Pad1.42x2.65mm_HandSolder
C5: 1u; C_0805_2012Metric
C6, C7, C8, C9, C11, C12: 100n; C_0805_2012Metric
C13, C14: C; C_0805_2012Metric
C17, C18, C19, C20: C_Small; C_0805_2012Metric
C21: 10uF; C_1210_3225Metric_Pad1.42x2.65mm_HandSolder
J1: Conn_01x24_Female; TE_2-1734839-4_1x24-1MP_P0.5mm_Horizontal_reversed_pinout
J2: Conn_01x03_Female; PinHeader_1x03_P1.00mm_Vertical_SMD_Pin1Left
J3: Conn_01x27_Female; PinHeader_1x27_P2.54mm_Vertical
JP1: SolderJumper_2_Open; SolderJumper-2_P1.3mm_Open_RoundedPad1.0x1.5mm
L1: 22uH; L_Coilcraft_LPS5030
R1, R3, R4: 10k; R_0805_2012Metric
R2: 910k; R_0805_2012Metric
R5, R6, R7, R8, R9, R19, R20, R21: 100k; R_0805_2012Metric
R10: 49R; R_0805_2012Metric
R11: 120k; R_0805_2012Metric
R12: 18k; R_0805_2012Metric
R13, R14: 4k7; R_0805_2012Metric
R15, R22, R23: R_Small; R_0805_2012Metric
SW1: AC_ON; fx502p_keypad
SW2: A; fx502p_keypad
SW3: g; fx502p_keypad
SW4: m; fx502p_keypad
SW5: s; fx502p_keypad
SW6: shft; fx502p_keypad
SW7: mode; fx502p_keypad
SW8: b; fx502p_keypad
SW9: h; fx502p_keypad
SW10: n; fx502p_keypad
SW11: t; fx502p_keypad
SW12: del; fx502p_keypad
SW13: up; fx502p_keypad
SW14: c; fx502p_keypad
SW15: i; fx502p_keypad
SW16: o; fx502p_keypad
SW17: u; fx502p_keypad
SW18: y; fx502p_keypad
SW19: down; fx502p_keypad
SW20: d; fx502p_keypad
SW21: j; fx502p_keypad
SW22: p; fx502p_keypad
SW23: v; fx502p_keypad
SW24: z; fx502p_keypad
SW25: left; fx502p_keypad
SW26: e; fx502p_keypad
SW27: k; fx502p_keypad
SW28: q; fx502p_keypad
SW29: w; fx502p_keypad
SW30: spc; fx502p_keypad
SW31: right; fx502p_keypad
SW32: f; fx502p_keypad
SW33: L; fx502p_keypad
SW34: r; fx502p_keypad
SW35: x; fx502p_keypad
SW36: exe; fx502p_keypad
TR1: Si2302CDS-n-channel; SOT-23
U1: Pico; RPi_Pico_SMD
U2: 74HC595; SOIC-16_3.9x9.9mm_P1.27mm
U3: Regulator_Switching_MT3608; SOT-23-6
U4: 74LS165; SOIC-16_3.9x9.9mm_P1.27mm
U5: MCP7940N-xSN; SO-8_3.9x4.9mm_P1.27mm
U6, U7: 74LS245; TSSOP-20_4.4x6.5mm_P0.65mm
U10, U11: AMS1117-3.3; SOT-223-3_TabPin2
Y1: 32k768Hz; Crystal_SMD_3215-2Pin_3.2x1.5mm

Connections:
+3V3: C1.1, C3.1, C4.1, C5.1, C6.1, C7.1, C8.1, C9.1, C11.1, C12.1, J1.5, J1.6, J3.27, L1.1, R3.1, R4.1, R13.1, R14.1, R15.1, SW1.1, U2.10, U2.16, U3.4, U3.5, U4.16, U5.8, U6.1, U6.20, U7.20
DRV_HV: TR1.1, U1.34
GND: C1.2, C2.2, C3.2, C5.2, C6.2, C7.2, C8.2, C9.2, C11.2, C12.2, C13.2, C14.2, C17.2, C18.2, C19.2, C20.2, J1.1, J1.2, J1.3, J1.7, J1.8, J1.11, J1.12, J1.16, J1.17, J1.18, J1.19, J1.20, J1.24, J2.2, J3.1, R1.2, R2.2, R5.2, R6.2, R7.2, R8.2, R9.2, R19.2, R20.2, R21.2, R23.2, TR1.2, U1.3, U1.8, U1.13, U1.18, U1.23, U1.28, U1.33, U1.42, U2.8, U2.13, U4.8, U4.10, U4.15, U5.4, U6.10, U6.19, U7.10, U7.19, U10.1, U11.1
K1: SW7.1, SW13.1, SW19.1, SW25.1, SW31.1, U2.15
K2: SW2.2, SW3.2, SW4.2, SW5.2, SW6.2, U2.1
K3: SW7.2, SW8.2, SW9.2, SW10.2, SW11.2, SW12.2, U2.2
K4: SW13.2, SW14.2, SW15.2, SW16.2, SW17.2, SW18.2, U2.3
K5: SW25.2, SW26.2, SW27.2, SW28.2, SW29.2, SW30.2, U2.4
K6: SW31.2, SW32.2, SW33.2, SW34.2, SW35.2, SW36.2, U2.5
K7: SW19.2, SW20.2, SW21.2, SW22.2, SW23.2, SW24.2, U2.6
LATCHIN: U1.25, U4.1
LATCHOUT: U1.29, U2.12
LS_DIR: R15.2, U7.1
unnamed: C2.1, J1.22
unnamed: C10.1, JP1.1, R11.1
unnamed: C4.2, C10.2, C21.2, C22.2, R10.2, R12.2, U3.2
unnamed: C13.1, U5.2, Y1.2
unnamed: C14.1, U5.1, Y1.1
unnamed: L1.2, U3.1
unnamed: J1.21, R2.1
unnamed: R10.1, TR1.3
unnamed: R11.2, R12.1, U3.3
unnamed: R22.2, R23.1, U5.3
OLED_RES: J1.9, U2.7
OLED_SCL: J1.13, R3.2, U1.22
OLED_SDA: J1.14, J1.15, R4.2, U1.21
P50: R5.1, U4.11
P51: R6.1, U4.12
P52: R7.1, SW6.1, SW12.1, SW18.1, SW24.1, SW30.1, SW36.1, U4.13
P53: R8.1, U4.14
P54: R9.1, SW4.1, SW10.1, SW16.1, SW22.1, SW28.1, SW34.1, U4.3
P55: R19.1, SW3.1, SW9.1, SW15.1, SW21.1, SW27.1, SW33.1, U4.4
P56: R20.1, SW2.1, SW8.1, SW14.1, SW20.1, SW26.1, SW32.1, U4.5
P57: R1.1, R21.1, SW1.2, U1.17, U4.6
P_SCLK: U1.14, U6.14
P_SD0: U1.1, U7.18
P_SD1: U1.2, U7.17
P_SD2: U1.4, U7.16
P_SD3: U1.5, U7.15
P_SD4: U1.6, U7.14
P_SD5: U1.7, U7.13
P_SD6: U1.9, U7.12
P_SD7: U1.10, U7.11
P_SMR: U1.16, U6.15
P_SOE: U1.15, U6.16
P_SPGM: U1.11, U6.18
P_SS: U1.12, U6.17
RTC_SCL: R14.2, U5.6
RTC_SDA: R13.2, U5.5
SCLK: J3.12, U6.6
SCLKIN: U1.26, U4.2
SCLKOUT: U1.31, U2.11
SD0: J3.2, U7.2
SD1: J3.3, U7.3
SD2: J3.4, U7.4
SD3: J3.5, U7.5
SD4: J3.6, U7.6
SD5: J3.7, U7.7
SD6: J3.8, U7.8
SD7: J3.9, U7.9
SDAIN: U1.27, U4.9
SDAOUT: U1.32, U2.14
SMR: J3.14, U6.5
SOE: J3.13, U6.4
SPGM: J3.10, U6.2
SS: J3.11, U6.3
SWCLK: J2.1, U1.41
SWD: J2.3, U1.43
VBAT: C17.1, C18.1, J3.26, R22.1, U10.3, U11.3
VOLED: C21.1, C22.1, J1.23, JP1.2
VccESP: C20.1, U11.2
VccPico: C19.1, U10.2
p53: SW5.1, SW11.1, SW17.1, SW23.1, SW29.1, SW35.1

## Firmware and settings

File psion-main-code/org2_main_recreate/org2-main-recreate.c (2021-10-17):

////////////////////////////////////////////////////////////////////////////////
//
// Psion Organiser II Main Board Re-creation
//
////////////////////////////////////////////////////////////////////////////////

#include <ctype.h>
#include <stdio.h>
#include <string.h>
#include <stdlib.h>
#include "pico/stdlib.h"
//#include "hardware/i2c.h"
//#include "hardware/pio.h"
//#include "hardware/clocks.h"
#include "hardware/uart.h"
#include "pico/multicore.h"

//#include "f_util.h"

//#include "ff.h"
//#include "ff_stdio.h"
//#include "hw_config.h"
//#include "my_debug.h"
//#include "rtc.h"
//#include "sd_card.h"

// Use this if breakpoints don't work
#define DEBUG_STOP {volatile int x = 1; while(x) {} }

// Are we compiling for the gadget breakout or the picopak?
#define PICOPAK 1

// Drop into a loop that displays key states and does nothing else
#define KEY_DEBUG_ONLY                0
#define TEST_IOPORT                   0

// Interrupts may muck up the pack interface, but it does seem to run with them enabled.
// If USB is ever to work then interrupts need to be enabled.
#define NO_INTERRUPTS_WHILE_POLLING   0
#define TEST_STDIO                    0

// Redefine pins to match our hardware
#define PICO_SD_CLK_PIN        5
#define PICO_SD_CMD_PIN       18
#define PICO_SD_DAT0_PIN      19
#define ENABLE_4_PIN           0

#define SUPPORT_ID_BYTE        1
#define PAK_ID_BYTE         0x01
#define READ_ONLY              0
#define INIT_PAK_MEMORY        1
#define FF_FIRST_BYTES         0

// Direct access to GPIO registers is faster, and we need speed
#define DIRECT_GPIO            1

// Number of buttons used for the menu system. The 'exit polling' button is not in this
// list, it is coded as a GPIO line as we don't want to waste time processing the menu
// buttons inthe fast polling loop

#define NUM_BUTTONS            3

// All organiser files are in this subdirectory on the SD card, just to keep things tidy
// and allow the card to be used for other things if needed.
#define PAK_DIR                "/PAK"

// Debounce
#define MAX_BUT_COUNT          6

bool sd_ok_flag = false;

// Do we use a polling loop of interrupts?
#define USE_INTERRUPTS         0
#define USE_POLLING            1

// For added speed, we poll the address counter stuff on the other core
#define MULTICORE_POLL         1

// The address into pak memory
#define PAK_ADDRESS (ss_address | ss_page)

// For the OLED display
const uint SDA_PIN             = 28;
const uint SCL_PIN             = 17;

#ifndef I2C_FUNCTIONS_H_
#define I2C_FUNCTIONS_H_

typedef unsigned char BYTE;

const int IO0_PIN       = 0;
const int IO1_PIN       = 1;
const int IO2_PIN       = 5;
const int IO3_PIN       = 16;
const int IO4_PIN       = 18;
const int IO5_PIN       = 19;
const int IO6_PIN       = 20;

const int OP_CLK_PIN    = 22;
const int IP_CLK_PIN    = 21;

// IO7 can also be used to measure battery voltage
const int IO7_PIN       = 26;

const int SLOT_SPGM_PIN = 2;
const int SLOT_SS_PIN   = 3;
const int SLOT_SCLK_PIN = 4;

const int SLOT_SOE_PIN  = 6;
const int SLOT_SMR_PIN  = 10;

const int SLOT_SD0_PIN  = 10;
const int SLOT_SD1_PIN  = 10;
const int SLOT_SD2_PIN  = 10;
const int SLOT_SD3_PIN  = 11;
const int SLOT_SD4_PIN  = 12;
const int SLOT_SD5_PIN  = 13;
const int SLOT_SD6_PIN  = 14;
const int SLOT_SD7_PIN  = 15;

const int LS_DIR_PIN    = 27;

volatile int ss_count = 0;
volatile int soe_state = 1;
volatile int ss_address = 0;
volatile int ss_page = 0;


// Memory that emulates a pak
typedef unsigned char BYTE;
typedef void (*FPTR)();
typedef void (*CMD_FPTR)(char *cmd);

// The tracing was used for low level analysis of the protocol
#define TRACE_LENGTH 8192
BYTE trace[TRACE_LENGTH];

int trace_i = 0;
#define TRACE(XX) if(trace_i != (TRACE_LENGTH-1)) {trace[trace_i++] = XX; trace_i %= TRACE_LENGTH;}
//#define TRACE(XX)

//#define WRITE_TRAP if( (PAK_ADDRESS + data) == 0)  while(1);

#define WRITE_TRAP

#define PAK_MEMORY_SIZE  65536
//#define PAK_MEMORY_SIZE  32768

// Allow a file to be selected. The file name will be stored for a later 'read' command.

int file_offset = 0;
int max_filenum = 0;

// File names for paks that are written to SD card
#define FILE_PAGE 7
#define PAK_FILE_NAME_FORMAT "pak%05d.opk"
#define PAK_FILE_NAME_GLOB   "pak*.opk"

// I2C Port descriptor
typedef struct _I2C_PORT_DESC
{
  unsigned char sdaport;
  unsigned char sdabit;
  unsigned char sclport;
  unsigned char sclbit;
} I2C_PORT_DESC;


// Slave device descriptor
typedef struct _I2C_SLAVE_DESC
{
  I2C_PORT_DESC *port;             // Port the device is on
  unsigned char slave_7bit_addr;        // SLave address
} I2C_SLAVE_DESC;


#if PICOPAK
#define MENU_MAX  3
#else
#define MENU_MAX  6
#endif

int menu_offset = 0;

typedef struct _BUTTON
{
  int     count;
  bool pressed;
  bool last_pressed;   // For edge detection
  FPTR    event_fn;
} BUTTON;

BUTTON buttons[NUM_BUTTONS];
enum ELEMENT_TYPE
  {
   BUTTON_ELEMENT = 10,
   SUB_MENU,
   MENU_END,
  };

struct MENU_ELEMENT
{
  enum ELEMENT_TYPE type;
  char *text;
  void *submenu;
  void (*function)(struct MENU_ELEMENT *e);
};

void button_display(struct MENU_ELEMENT *e);
void button_list(struct MENU_ELEMENT *e);
//void but_ev_file_up();
//void but_ev_file_down();
void but_ev_file_select();

void loop_delay(int delay)
{
  volatile x, y;

  for(x=0; x<delay; x++)
    {
      for(y=0; y<10; y++)
	{
	}
    }
}

int menuloop_done = 0;

#if !INIT_PAK_MEMORY
volatile BYTE pak_memory[PAK_MEMORY_SIZE];
#else

volatile BYTE pak_memory[] =
  {
   // ASSEMBLER_EMBEDDED_CODE_START
0x46,0x04,0x01,0x0A,0x00,0x0A,0x00,0x19,0xFF,0xFF,0x09,0x81,0x4D,0x41,0x49,0x4E,
0x20,0x20,0x20,0x20,0x90,0x02,0x80,0x03,0xB1,0x03,0x55,0x00,0x00,0x00,0x0A,0x00,
0x03,0x00,0x62,0x00,0xA4,0x00,0xCE,0x08,0x4C,0x41,0x54,0x4F,0x55,0x54,0x41,0x41,
0x01,0xA7,0x08,0x4C,0x41,0x54,0x4F,0x55,0x54,0x30,0x30,0x01,0xAE,0x08,0x4C,0x41,
0x54,0x4F,0x55,0x54,0x46,0x46,0x01,0xB5,0x05,0x4C,0x41,0x54,0x49,0x4E,0x01,0x45,
0x09,0x50,0x49,0x43,0x4F,0x4F,0x55,0x54,0x41,0x41,0x01,0x05,0x09,0x50,0x49,0x43,
0x4F,0x4F,0x55,0x54,0x30,0x30,0x01,0x64,0x09,0x50,0x49,0x43,0x4F,0x4F,0x55,0x54,
0x46,0x46,0x01,0x6B,0x06,0x50,0x49,0x43,0x4F,0x49,0x4E,0x01,0x64,0xCE,0x00,0x0C,
0xBD,0x00,0x93,0xCE,0x00,0x17,0xBD,0x00,0x93,0xCE,0x00,0x22,0xBD,0x00,0x93,0xCE,
0x00,0x2D,0xBD,0x00,0x93,0xCE,0x00,0x35,0xBD,0x00,0x93,0xCE,0x00,0x41,0xBD,0x00,
0x93,0xCE,0x00,0x4D,0xBD,0x00,0x93,0xCE,0x00,0x59,0xBD,0x00,0x93,0x39,0xE6,0x00,
0xCB,0x03,0x4F,0xDD,0x41,0xCC,0x21,0x87,0x3F,0x6D,0xC6,0xFF,0x3F,0x65,0x39,0xCE,
0x00,0x0C,0x3F,0x67,0xCE,0x00,0x17,0x3F,0x67,0xCE,0x00,0x22,0x3F,0x67,0xCE,0x00,
0x2D,0x3F,0x67,0xCE,0x00,0x35,0x3F,0x67,0xCE,0x00,0x41,0x3F,0x67,0xCE,0x00,0x4D,
0x3F,0x67,0xCE,0x00,0x59,0x3F,0x67,0x0C,0x39,0x0D,0x39,0x36,0x4F,0xC6,0x03,0x3F,
0x62,0x72,0x40,0x17,0x86,0xFF,0x97,0x01,0x32,0x97,0x03,0x72,0x08,0x17,0x71,0xFD,
0x17,0x71,0xBF,0x17,0x71,0xBF,0x17,0x71,0xBF,0x17,0x71,0xBF,0x17,0x72,0x40,0x17,
0x72,0x40,0x17,0x72,0x40,0x17,0x7F,0x00,0x01,0x71,0xF7,0x17,0x72,0x40,0x17,0x39,
0x86,0xAA,0xBD,0x00,0xD0,0x0C,0x39,0x4F,0xC6,0x03,0x3F,0x62,0x72,0x40,0x17,0x86,
0xFF,0x7F,0x00,0x01,0x71,0xF7,0x17,0x72,0x02,0x17,0x71,0xFE,0x17,0x71,0xBF,0x17,
0x71,0xBF,0x17,0x71,0xBF,0x17,0x71,0xBF,0x17,0x96,0x03,0x36,0x72,0x40,0x17,0x72,
0x40,0x17,0x72,0x40,0x17,0x7F,0x00,0x01,0x71,0xF7,0x17,0x72,0x40,0x17,0x32,0x39,
0xCE,0x00,0x00,0x3F,0x14,0x86,0xAA,0xBD,0x01,0x0C,0x36,0x3F,0x6F,0x0C,0x49,0x4C,
0x41,0x54,0x3A,0x25,0x79,0x00,0x3F,0x4B,0x5D,0x27,0xE5,0x3F,0x48,0x0C,0x39,0x86,
0x00,0xBD,0x00,0xD0,0x0C,0x39,0x86,0xFF,0xBD,0x00,0xD0,0x0C,0x39,0x36,0x4F,0xC6,
0x03,0x3F,0x62,0x72,0x40,0x17,0x86,0xFF,0x97,0x01,0x32,0x97,0x03,0x72,0x08,0x17,
0x72,0x02,0x17,0x72,0x01,0x17,0x71,0xBF,0x17,0x71,0xBF,0x17,0x71,0xBF,0x17,0x72,
0x40,0x17,0x72,0x40,0x17,0x72,0x40,0x17,0x7F,0x00,0x01,0x71,0xF7,0x17,0x72,0x40,
0x17,0x39,0x86,0xAA,0xBD,0x01,0x72,0x0C,0x39,0x86,0x00,0xBD,0x01,0x72,0x0C,0x39,
0x86,0xFF,0xBD,0x01,0x72,0x0C,0x39,0x00,0x00,0x00,0x00,0x00,0x00,0x00,0x00,0x00,
0x00,0x00,0x00,0x00,0x00,0x00,0x00,0x00,0x00,0x00,0x00,0x00,0x00,0x00,0x00,0x00,
0x00,0x00,0x00,0x00,0x00,0x00,0x00,0x00,0x00,0x00,0x00,0x00,0x00,0x00,0x00,0x00,
0x00,0x00,0x00,0x00,0x00,0x00,0x00,0x00,0x00,0x00,0x00,0x00,0x00,0x00,0x00,0x00,
0x00,0x00,0x00,0x00,0x00,0x00,0x00,0x00,0x00,0x00,0x00,0x00,0x00,0x00,0x00,0x00,
0x00,0x00,0x00,0x00,0x00,0x00,0x00,0x00,0x0F,0x00,0x00,0x00,0x00,0x00,0x00,0x00,
0x00,0x00,0x00,0x00,0x00,0x00,0x00,0x00,0x00,0x00,0x00,0x00,0x00,0x00,0x00,0x00,
0x00,0x00,0x00,0x00,0x00,0x00,0x00,0x00,0x00,0x00,0x00,0x00,0x00,0x00,0x00,0x00,
0x00,0x00,0x00,0x00,0x00,0x00,0x00,0x00,0x00,0x00,0x00,0x00,0x00,0x00,0x00,0x00,
0x00,0x00,0x00,0x00,0x00,0x00,0x00,0x00,0x00,0x00,0x00,0x00,0x00,0x00,0x00,0x00,
0x00,0x00,0x00,0x00,0x00,0x00,0x00,0x00,0x00,0x00,0x00,0x00,0x00,0x00,0x00,0x00,
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
// ASSEMBLER_EMBEDDED_CODE_END
  };

// Pre-initialised pack memory.
// This is a copy of the V2.5 Comms link ROM, just as a test of the board.
// For proper applications this will contain whatever code is needed to drive the
// hardware.

volatile BYTE pak_memory_comms[] =
  {
   0x6a,0x04,0x01,0xc0,0x25,0xc0,0x00,0x19,0xff,0xff,
   0x09,0x81,0x4d,0x41,0x49,0x4e,0x20,0x20,0x20,0x20,0x90,0x02,0x80,0x57,0xcd,0x10,
   0x39,0x00,0x00,0x00,0xc0,0x25,0x14,  0x06,0x4b,0x01,0xa7,0x01,0xc5,0x06,0x70,0x06,
   0x7a,0x06,0xa8,0x06,0xad,0x06,0xa3,0x06,0x85,0x06,0x8a,0x06,0x8f,0x06,0x62,0x06,
   0x9e,0x06,0xbe,0x06,0x94,0x06,0xfc,0x06,0xf7,0x06,0xb2,0x06,0x75,0x06,0x99,0xff,
   0xff,0xff,0xff,0xff,0xff,0xff,0xff,0xff,0xff,0xff,0xff,0xff,0xff,0xff,0xff,0xff,
   0xff,0xff,0xff,0xff,0xff,0xff,0xff,0xff,0xff,0xff,0xff,0xff,0xff,0xff,0xff,0xff,
   0xff,0xff,0xff,0xff,0xff,0xff,0xff,0xff,0xff,0xff,0xff,0xff,0xff,0xff,0xff,0xff,
   0xff,0xff,0xff,0xff,0xff,0xff,0xff,0xff,0xff,0xff,0xff,0xff,0xff,0xff,0xff,0xff,
   0xff,0xff,0xff,0xff,0xff,0xff,0xff,0xff,0xff,0xff,0xff,0xff,0xff,0xff,0xff,0xff,
   0xff,0xff,0xff,0xff,0xff,0xff,0xff,0xff,0xff,0xff,0xff,0xff,0xff,0xff,0xff,0xff,
   0xff,0xff,0xff,0xff,0xff,0xff,0xff,0xff,0xff,0xff,0xff,0xff,0xff,0xff,0xff,0xff,
   0xff,0xff,0xff,0xff,0xff,0xff,0xff,0xff,0xff,0xff,0xff,0xff,0xff,0xff,0xff,0xff,
   0x00,0x00,0x00,0x00,0x34,0x00,0x00,0x00,0x00,0x00,0x00,0xff,0x00,0xff,0xff,0xff,
   0xff,0xff,0xff,0xff,0xff,0xff,0xff,0xc7,0xaf,0xa0,0x97,0x5f,0x2f,0x17,0x0b,0x05,
   0x02,0xff,0xff,0xff,0xff,0x02,0xff,0xff,0xff,0xff,0xff,0xff,0xff,0xff,0xff,0xff,
   0xff,0xff,0xff,0xff,0xff,0xff,0x00,0xff,0xff,0xff,0xff,0x05,0x43,0x4f,0x4d,0x4d,
   0x53,0x07,0x2b,0x02,0x07,0xff,0x02,0xbd,0xff,0x04,0x82,0xff,0x04,0xef,0xff,0x02,
   0x03,0xff,0x05,0xe9,0xff,0x08,0xb6,0x04,0x09,0x8d,0x04,0x0b,0xc3,0x10,0x0b,0xd3,
   0x10,0x0c,0x01,0x10,0x0c,0x29,0x10,0x04,0x4c,0x53,0x45,0x54,0x05,0x54,0x52,0x49,
   0x47,0x24,0x05,0x58,0x46,0x45,0x4f,0x46,0x05,0x58,0x46,0x50,0x4f,0x53,0x05,0x58,
   0x46,0x50,0x55,0x54,0x05,0x58,0x4c,0x43,0x4f,0x4e,0x05,0x58,0x4c,0x44,0x49,0x53,
   0x05,0x58,0x4c,0x50,0x55,0x54,0x06,0x4c,0x50,0x52,0x49,0x4e,0x54,0x06,0x58,0x46,
   0x47,0x45,0x54,0x24,0x06,0x58,0x46,0x4f,0x50,0x45,0x4e,0x06,0x58,0x4c,0x47,0x45,
   0x54,0x24,0x06,0x58,0x4d,0x4c,0x4f,0x41,0x44,0x06,0x58,0x54,0x52,0x45,0x43,0x56,
   0x06,0x58,0x54,0x53,0x45,0x4e,0x44,0x07,0x4c,0x49,0x4e,0x50,0x55,0x54,0x24,0x07,
   0x58,0x46,0x43,0x4c,0x4f,0x53,0x45,0x00,0x07,0x4b,0x11,0x78,0x07,0x4b,0x12,0x15,
   0x07,0x4b,0x16,0xc1,0x07,0x4b,0x1f,0x3c,0x07,0x4b,0x24,0xb5,0x07,0x4b,0x3d,0xd2,
   0x07,0x4b,0x3e,0x86,0x07,0x4b,0x54,0xc9,0xde,0x47,0x3c,0xde,0x4b,0x3c,0xc6,0x01,
   0xbd,0x02,0xbd,0xce,0x00,0xea,0x3f,0x67,0xfc,0x00,0xb8,0xf7,0x21,0x72,0x38,0xdf,
   0x4b,0x38,0xdf,0x47,0x0c,0x39,0xdf,0xe4,0xce,0x01,0x16,0xdf,0xea,0x86,0x02,0x97,
   0xe8,0x7c,0x00,0xe8,0xde,0xea,0xdf,0xe6,0xa6,0x00,0x27,0x20,0x16,0x5c,0x3a,0xdf,
   0xea,0xde,0xe4,0xa1,0x00,0x25,0xea,0x22,0x13,0x5a,0x27,0x12,0x08,0x3c,0xa6,0x00,
   0xde,0xe6,0x08,0xdf,0xe6,0xa1,0x00,0x38,0x22,0xd7,0x27,0xed,0x0d,0x39,0xd6,0xe8,
   0x86,0xc0,0x0c,0x39,0x7f,0x00,0xb0,0x39,0x7f,0x00,0xb6,0xc5,0x04,0x27,0x03,0x7f,
   0x00,0xb1,0xce,0x00,0xb5,0xa6,0x00,0x84,0xfc,0xc4,0x03,0x1b,0x8a,0x04,0xa7,0x00,
   0x85,0x08,0x26,0x25,0x62,0x08,0x00,0x07,0xd6,0x7c,0xfd,0x00,0xbc,0x0f,0x5f,0xd7,
   0x7c,0xcc,0x05,0x0e,0xfd,0x20,0x54,0xcc,0x05,0x63,0xfd,0x20,0x52,0xcc,0x05,0x1b,
   0xfd,0x20,0x4c,0xcc,0x03,0xc1,0xfd,0x20,0x48,0x36,0x6b,0x10,0x00,0x26,0x4d,0x3c,
   0x8d,0x52,0x38,0x25,0x48,0x7b,0x01,0x15,0x26,0x46,0x0f,0x72,0x40,0x17,0x72,0x08,
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
  };


BYTE pak_memory_angling[PAK_MEMORY_SIZE] =
  {
   0x78,0x04,0x56,0x00,0x03,0x02,0x35,0x46,0x06,0x4c,
   0x09,0x81,0x4d,0x41,0x49,0x4e,0x20,0x20,0x20,0x20,0x90,0x09,0x83,0x46,0x49,0x53,
   0x48,0x20,0x20,0x20,0x20,0x00,0x02,0x80,0x01,0x26,0x01,0x22,0x00,0x29,0x00,0xfc,
   0x00,0x00,0x13,0x02,0x59,0x25,0x00,0xff,0xe9,0x03,0x44,0x52,0x24,0x02,0xff,0xe6,
   0x02,0x46,0x24,0x02,0xff,0xdc,0x00,0x00,0x00,0x06,0xff,0xe5,0x02,0xff,0xdb,0x08,
   0x00,0x00,0x0f,0xff,0xdc,0x24,0x04,0x46,0x49,0x53,0x48,0x20,0x02,0x20,0x01,0x7d,
   0x06,0x45,0x58,0x49,0x53,0x54,0x24,0x81,0x02,0xff,0xdc,0x24,0x00,0x4a,0x7e,0x00,
   0x32,0x0d,0xff,0xd9,0x24,0x10,0x43,0x52,0x45,0x41,0x54,0x45,0x2d,0x46,0x49,0x4c,
   0x45,0x2c,0x51,0x55,0x49,0x54,0x98,0x7f,0x00,0xff,0xd9,0x022,0x00,0x01,0x2c,0x7e,
   0x00,0x10,0x20,0x00,0x7d,0x06,0x46,0x49,0x53,0x48,0x43,0x52,0x84,0x51,0x00,0x03,
   0x7b,0x20,0x00,0x7d,0x06,0x46,0x49,0x53,0x48,0x4f,0x50,0x84,0x20,0x00,0x7d,0x06,
   0x4d,0x41,0x44,0x55,0x44,0x47,0x84,0x0d,0xff,0xd7,0x24,0x20,0x41,0x44,0x44,0x2d,
   0x4e,0x45,0x57,0x2d,0x46,0x49,0x53,0x48,0x2c,0x53,0x45,0x41,0x52,0x43,0x48,0x2c,
   0x52,0x45,0x50,0x4f,0x52,0x54,0x2c,0x55,0x54,0x49,0x4c,0x53,0x98,0x7f,0x00,0xff,
   0xd7,0x22,0x00,0x01,0x2c,0x7e,0x00,0x14,0x20,0x00,0x7d,0x07,0x46,0x49,0x53,0x48,
   0x41,0x44,0x44,0x84,0x51,0xff,0xc2,0x51,0x00,0x55,0x00,0xff,0xd7,0x22,0x00,0x02,
   0x2c,0x7e,0x00,0x14,0x20,0x00,0x7d,0x07,0x46,0x49,0x53,0x48,0x53,0x45,0x45,0x84,
   0x51,0xff,0xa6,0x51,0x00,0x39,0x00,0xff,0xd7,0x22,0x00,0x03,0x2c,0x7e,0x00,0x14,
   0x20,0x00,0x7d,0x07,0x46,0x49,0x53,0x48,0x52,0x45,0x50,0x84,0x51,0xff,0x8a,0x51,
   0x00,0x1d,0x00,0xff,0xd7,0x22,0x00,0x04,0x2c,0x7e,0x00,0x12,0x20,0x00,0x7d,0x05,
   0x55,0x54,0x49,0x4c,0x53,0x84,0x51,0xff,0x70,0x51,0x00,0x03,0x7b,0x7b,0x00,0x00,
   0x09,0x83,0x46,0x49,0x53,0x48,0x41,0x44,0x44,0x20,0x00,0x02,0x80,0x06,0x11,0x06,
   0x0d,0x00,0x3a,0x05,0xee,0x00,0x00,0x00,0x00,0x00,0x00,0x12,0xff,0xf4,0x06,0xff,
   0xe6,0x04,0xff,0xe2,0x02,0xff,0xde,0x02,0xff,0xd8,0x04,0xff,0xc6,0x10,0x00,0x00,
   0x4e,0x24,0x0f,0x45,0x58,0x45,0x20,0x74,0x6f,0x20,0x63,0x6f,0x6e,0x74,0x69,0x6e,
   0x75,0x65,0x71,0x73,0x24,0x0d,0x43,0x4c,0x45,0x41,0x52,0x20,0x74,0x6f,0x20,0x71,
   0x75,0x69,0x74,0x71,0x73,0x0d,0xff,0xfc,0x91,0x7f,0x00,0xff,0xfc,0x22,0x00,0x0d,
   0x2b,0x7e,0x00,0x03,0x7b,0x4e,0x62,0x24,0x04,0x44,0x41,0x59,0x24,0x1f,0x00,0xb9,
   0x22,0x00,0x10,0xc0,0x81,0x0f,0xff,0xc7,0x24,0x04,0x44,0x41,0x59,0x24,0x1c,0x00,
   0x81,0x24,0x04,0x44,0x41,0x59,0x24,0x1f,0x00,0x6b,0x24,0x04,0x44,0x41,0x59,0x24,
   0x1c,0x00,0x02,0xff,0xc7,0x49,0x7e,0x00,0x85,0x53,0xff,0xff,0x24,0x04,0x44,0x41,
   0x59,0x24,0x1f,0x00,0x24,0x04,0x44,0x41,0x59,0x24,0x1c,0x00,0x22,0x00,0x10,0xc0,
   0x81,0x22,0x00,0x03,0x6a,0x0f,0xff,0xe3,0x8c,0x86,0x22,0x00,0x02,0xbc,0x81,0x0f,
   0xff,0xdf,0x9a,0x86,0x22,0x00,0x02,0xbc,0x81,0x0f,0xff,0xd9,0xa1,0x86,0x22,0x00,
   0x04,0xbc,0x81,0x22,0x00,0x01,0x22,0x00,0x02,0x4c,0x0f,0xff,0xe3,0x6b,0x22,0x00,
   0x04,0x22,0x00,0x02,0x4c,0x0f,0xff,0xdf,0x6b,0x22,0x00,0x08,0x22,0x00,0x02,0x4c,
   0x0f,0xff,0xd9,0x6b,0x24,0x01,0x44,0x1e,0x00,0x02,0xff,0xe3,0xb5,0x02,0xff,0xdf,
   0xb5,0x22,0x00,0x64,0x86,0x3e,0x3c,0x02,0xff,0xd9,0xb5,0x22,0x27,0x10,0x86,0x3e,
   0x3c,0x80,0x22,0x00,0x01,0x6a,0x53,0x00,0x00,0x51,0x00,0x24,0x24,0x01,0x44,0x1e,
   0x00,0xa1,0x86,0x80,0x24,0x01,0x44,0x1e,0x00,0x24,0x01,0x44,0x1b,0x00,0x22,0x27,
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
  };
#endif

////////////////////////////////////////////////////////////////////////////////
//
#if 0
typedef struct {
  FATFS fatfs;
  char const *const name;
} fatfs_dscr_t;

static fatfs_dscr_t fatfs_dscrs[2] = {{.name = "0:"}, {.name = "1:"}};
static FATFS *get_fs_by_name(const char *name) {
  for (size_t i = 0; i < count_of(fatfs_dscrs); ++i) {
    if (0 == strcmp(fatfs_dscrs[i].name, name)) {
      return &fatfs_dscrs[i].fatfs;
    }
  }
  return NULL;

}

#endif

static bool logger_enabled;
static const uint32_t period = 1000;
static absolute_time_t next_time;

void button_select_file(struct MENU_ELEMENT *e);

////////////////////////////////////////////////////////////////////////////////



// I2C functions
void i2c_release(I2C_PORT_DESC *port);
void i2c_delay(I2C_PORT_DESC *port);
void i2c_sda_low(I2C_PORT_DESC *port);
void i2c_sda_high(I2C_PORT_DESC *port);
void i2c_scl_low(I2C_PORT_DESC *port);
void i2c_scl_high(I2C_PORT_DESC *port);
void i2c_start(I2C_PORT_DESC *port);
void i2c_stop(I2C_PORT_DESC *port);
int i2c_send_byte(I2C_PORT_DESC *port, BYTE b);
int i2c_read_bytes(I2C_SLAVE_DESC *slave, int n, BYTE *data);
void i2c_send_bytes(I2C_SLAVE_DESC *slave, int n, BYTE *data);
#


#endif /* I2C_FUNCTIONS_H_ */


/*
 * i2c_functions.c
 *
 *  Created on: 23 Jul 2016
 *      Author: menadue
 */
//#include "chip.h"
//#include "board.h"
//#include "i2c_functions.h"


// I2C functions

// Release the bus
void i2c_release(I2C_PORT_DESC *port) {
  // All inputs
  gpio_set_dir(SDA_PIN,GPIO_OUT);
  gpio_set_dir(SCL_PIN,GPIO_OUT);
  gpio_put(SDA_PIN, 0);
  gpio_put(SCL_PIN, 0);
  
  //  Chip_GPIO_SetPinDIRInput(LPC_GPIO, port->sdaport, port->sdabit);
  //Chip_GPIO_SetPinDIRInput(LPC_GPIO, port->sclport, port->sclbit);
}

// Delay to slow down to I2C bus rates
void i2c_delay(I2C_PORT_DESC *port) {
  sleep_us(1);
  return;
  volatile int i;
  for(i=0; i<1; i++)
    {
    }
  
}

void i2c_sda_low(I2C_PORT_DESC *port)
{
  // Take SCL low by driving a 0 on to the bus
  gpio_set_dir(SDA_PIN,GPIO_OUT);
  gpio_put(SDA_PIN, 0);
  //Chip_GPIO_SetPinState(LPC_GPIO, port->sdaport, port->sdabit, 0);
  
  // Make sure bit is an output
  //Chip_GPIO_SetPinDIROutput(LPC_GPIO, port->sdaport, port->sdabit);
}

void i2c_sda_high(I2C_PORT_DESC *port)
{
  // Make sure bit is an input
  gpio_set_dir(SDA_PIN,GPIO_IN);
  //  gpio_put(SDA_PIN, 1);
  //  Chip_GPIO_SetPinDIRInput(LPC_GPIO, port->sdaport, port->sdabit);
}

void i2c_scl_low(I2C_PORT_DESC *port) {

  gpio_set_dir(SCL_PIN,GPIO_OUT);
  gpio_put(SCL_PIN, 0);
  
  //  Chip_GPIO_SetPinState(LPC_GPIO, port->sclport, port->sclbit, 0);

  // Make sure bit is an output
  //Chip_GPIO_SetPinDIROutput(LPC_GPIO, port->sclport, port->sclbit);
}

void i2c_scl_high(I2C_PORT_DESC *port)
{
  // Make sure bit is an input
  gpio_set_dir(SCL_PIN, GPIO_IN);
  //gpio_put(SCL_PIN, 1);
  //Chip_GPIO_SetPinDIRInput(LPC_GPIO, port->sclport, port->sclbit);
}

// Read ACK bit
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
int main()
{
  char line[80];

  stdio_init_all();

  printf("\nSetting GPIOs...");

  printf("\nSetting up OLED...");
    
  // Set up OLED display
  i2c_init(&i2c_bus_0);
    
  oled_setup(&oled0);

  int count = 0;

////////////////////////////////////////////////////////////////////////////////
#define UART_ID uart1 //uart0
#define BAUD_RATE 115200
#define DATA_BITS 8
#define STOP_BITS 1
#define PARITY    UART_PARITY_NONE

// We are using pins 0 and 1, but see the GPIO function select table in the
// datasheet for information on which other pins can be used.
#define UART_TX_PIN 8 //0
#define UART_RX_PIN 9 //1

  sleep_us(1000000);
  sleep_us(1000000);  
  gpio_set_function(UART_TX_PIN, GPIO_FUNC_UART);
  gpio_set_function(UART_RX_PIN, GPIO_FUNC_UART);
  uart_init(UART_ID, BAUD_RATE);
  uart_set_hw_flow(UART_ID, false, false);
  //uart_set_fifo_enabled(UART_ID, false);
  
  gpio_init(7);
  gpio_put(7, 1);
  gpio_set_dir(7, GPIO_OUT);
  
  gpio_init(10);
  gpio_set_dir(10, GPIO_IN);
  
  gpio_init(11);
  gpio_set_dir(11, GPIO_OUT);
  
  gpio_put(11, 1);
  sleep_us(100000);
  gpio_put(11, 0);

  printf("\nOrganiser 2 Main Board\n");
  stdio_flush();
  
  
  // Overall loop, which contains the polling loop and the menu loop
  oled_clear_display(&oled0);
  
  oled_set_xy(&oled0, 0,0);
  oled_display_string(&oled0, "Main Board Recreate");
    
  long cxx = 0L;
  char cmd[200];
  char *reply1 = "HTTP/1.1 200 OK\n\
Content-Type: text/html\n\
Connection: close\n\n\
<!DOCTYPE HTML>\n\
<html>\n\
Psion Organiser Recreation\n\
</html> ";
  
  char input_text[2000];
  int ip_i = 0;

  input_text[0] = '\0';

  
  while(1)
    {
      int c;
      cxx++;
	
      if( (cxx % 1000000) == 0 )
	{
	  //printf("\nSent");
	  //uart_puts(uart1, "\nAT\n");
	}
	
      c = getchar_timeout_us(0);
	
      if( c != PICO_ERROR_TIMEOUT )
	{
	  //printf("%c", c);
	  uart_putc(UART_ID, c);
	  if( c == 13 )
	    {
	      uart_putc(UART_ID, 10);
	    }
	}

      if( uart_is_readable (UART_ID) )
	{
	  char ch[2] = " ";
	  ch[0] = uart_getc(UART_ID);
	  printf("%c", ch[0]);
	    
	  // Add to input buffer
	  strcat(input_text, ch);

	  if( ch[0] == 10 )
	    {
	      input_text[0] = '\0';
	    }

	  if( ch[0] == 13 )
	    {
	      input_text[0] = '\0';
	    }
	  
	  if( strncmp(input_text, "ready", 5) == 0 )
	    {
	      printf("\nSetting up...");
	      
	      sleep_us(5000000);
	      sprintf(cmd, "AT+CIPMUX=1\r\n");
	      uart_puts(UART_ID, cmd);

	      sleep_us(1000000);
	      sprintf(cmd, "AT+CIPSERVER=1,80\r\n");
	      uart_puts(UART_ID, cmd);
	      
	      input_text[0] = '\0';
	    }
		  
	  
	  if( strncmp(input_text, "+IPD", 4) == 0 )
	    {
	      printf("\nPage request...\n");
	      
	      // Wait for a second and then send reply
	      sleep_us(2000000);
	      
	      sprintf(cmd, "AT+CIPSEND=0,%d\r\n", strlen(reply1));
	      uart_puts(UART_ID, cmd);
	      printf("%s", cmd);
	      
	      sleep_us(1000000);
	      uart_puts(UART_ID, reply1);
	      printf("%s\n", reply1);
	      
	      sleep_us(1000000);

	      uart_puts(UART_ID, "AT+CIPCLOSE=0\r\n");

	      input_text[0] = '\0';
	    }
	}
    }
}

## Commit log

2021-09-14 Initial checkin
    [a.sch, b.sch, file612F7BBD.sch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]
2021-09-14 Updates to control PCB schematic
    [psion-org2-main.sch]
2021-09-14 More updates
    [a.sch, file612F7BBD.sch, oled.sch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]
2021-09-16 Schematic updates
    [a.sch, file612F7BBD.sch, psion-org2-main.sch]
2021-10-17 Added start of code for main board replacement. Wifi server
    [psion-org2-main.sch]
2021-11-02 PCB updates
    [file612F7BBD.sch, oled.sch, power.sch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]
2021-11-07 Last commit before splitting to two PCBs
    [a.sch, file612F7BBD.sch, psion-org2-main.kicad_pcb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]
2021-11-08 Created power PCB
    [a.sch, b.sch, file612F7BBD.sch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]
2021-11-08 Updates to power PCB
    [psion-org2-power.kicad_pcb, psion-org2-power.sch]
2021-11-09 Updates to both PCBs
    [psion-org2-main.kicad_pcb, psion-org2-main.sch, psion-org2-power.sch]
2021-11-11 Added second connector, eeprom on power pcb
    [a.sch, file612F7BBD.sch, psion-org2-main.kicad_pcb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]
2021-11-12 Start of PCB layout
    [psion-org2-main.kicad_pcb, psion-org2-main.sch, psion-org2-power.kicad_pcb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]
2021-11-12 First main PCB layout
    [psion-org2-main-B_Cu.gbr, psion-org2-main-B_Mask.gbr, psion-org2-main-B_Paste.gbr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]
2021-11-13 First layouts for fabrication
    [psion-org2-main-B_Cu.gbr, psion-org2-main-B_Mask.gbr, psion-org2-main-B_Paste.gbr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]
2021-11-13 Small updates and sent to fab
    [psion-org2-main-B_Cu.gbr, psion-org2-main-B_Mask.gbr, psion-org2-main-B_Paste.gbr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]
2021-12-05 Added fab1 archive and small fixes to emulator
    [file612F7BBD.sch, psion-org2-main.kicad_pcb]
2021-12-07 Added bank switching for LZ
2021-12-08 Updates after fab1
    [file612F7BBD.sch, psion-org2-main.sch]
2021-12-25 Annotated ROM listin gupdate
    [psion-org2-main.sch, psion-org2-power.sch]
2021-12-27 V1.1 started
    [file612F7BBD.sch, psion-org2-main.kicad_pcb, psion-org2-main.sch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]
2021-12-28 V1.1 PCBs
    [psion-org2-main.kicad_pcb, psion-org2-main.sch, psion-org2-power.kicad_pcb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]
2021-12-28 fab2 V1.1
    [psion-org2-main-B_Cu.gbr, psion-org2-main-B_Mask.gbr, psion-org2-main-B_Paste.gbr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]
2022-07-25 Updated missing values on schematics, pushed those through to the PCB and created BOM .csv files for those schematics. Created .pdf files for schematics to mitigate the missing library problem of Kic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
    [psion-org2-main.csv, psion-org2-main.kicad_pcb, psion-org2-main.sch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]
2022-08-20 Added power board with VPP 21V supply
    [a.sch, b.sch, file612F7BBD.sch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]
2022-08-21 Fixed comment typo. Reverted schematic to previous version (966dcfb2f9e5fb2f0f6e9c85d958500d25748731) as a change (7bf7705c572b4e37423d66cfa6dac4b195edf464) somehow managed to create a bad hierarchic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
    [file612F7BBD.sch, psion-org2-main.kicad_pcb, psion-org2-main.sch]
